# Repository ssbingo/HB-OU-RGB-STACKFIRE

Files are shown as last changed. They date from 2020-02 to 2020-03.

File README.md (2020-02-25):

# HB-OU-RGB-STACKFIRE - Kaminfeuer Leuchte

Viele Projekte haben sich mit der Steuerung von WS2812B-LED's befasst. 
Eigentlich wollte ich aus dem Tee-Licht-Projekt vom [pafra-123](https://github.com/pafra-123/HB_LED_Teelicht) einen kleinen Kamin für die Weihnachtskrippe machen.
Daraus enstand der Gedanke an eine etwas größere Kamin-/Lagerfeuer-Simulation. 
Irgendwo fand ich dann das Projekt einer Nachttischlampe.
Im Großen und Ganzen ganz hübsch, mir jedoch zu klein. Ich wollte es als Raumdeko, als Hingucker bei der Gartenparty und als gemütliches Highlight abends vor dem Wohnwagen. Und ich wollte es Homematic-gebunden haben. Da fand ich den [RGB-Controler](https://github.com/jp112sdl/HB-UNI-RGB-LED-CTRL) von Jérôme(jp112sdl).<br>
So verschmolzen Teile diverser Projekte zu einem Neuen.

## Bilder

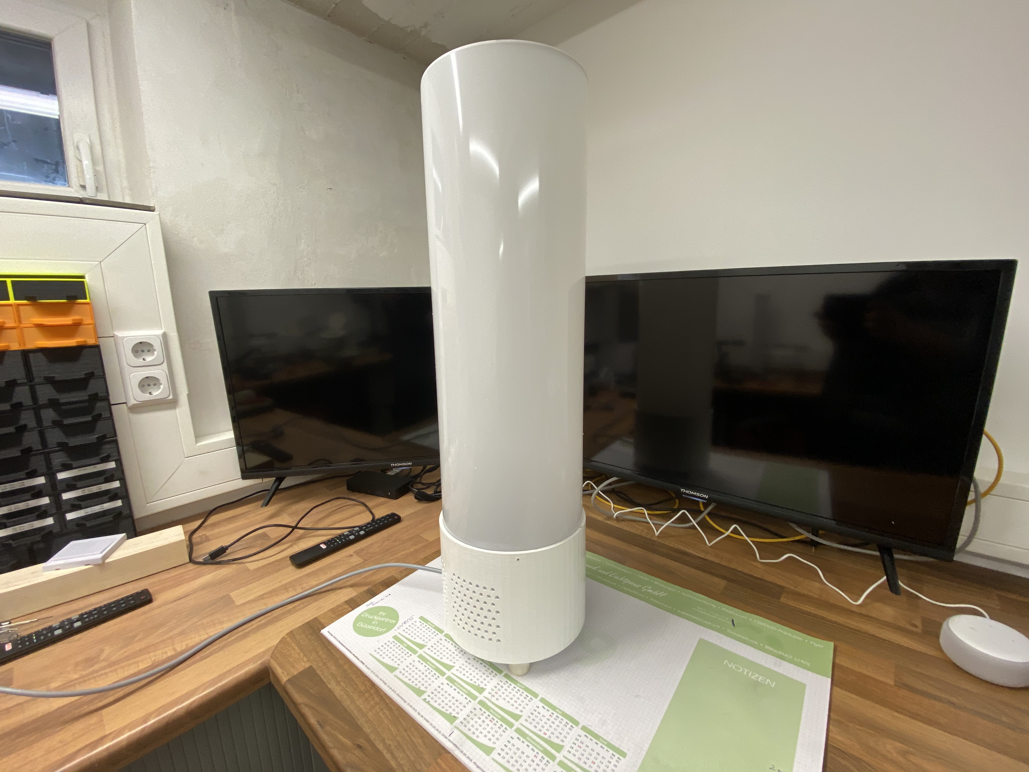
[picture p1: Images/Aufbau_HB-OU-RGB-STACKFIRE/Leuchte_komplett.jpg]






## Konfiguration
### auf der Platine
Die aktuelle Version der PCB verfügt über einen 2-fach Jumper J4 (VCC). Dieser ermöglicht es, die Leuchte ohne das [AZDelivery 5 x 220V zu 5V Mini-Netzteil](https://www.amazon.de/gp/product/B07V7GHK51/ref=ppx_yo_dt_b_asin_title_o06_s00?ie=UTF8&psc=1) zu betreiben. Die Schaltung wird dann über das erste Netzteil der Stripes mit versorgt.<br>
:exclamation:Die Jumper dürfen auf keinen Fall gesteckt werden, wenn das Mini-Netzteil auf der Platine verbaut ist.
Mit dem Einsatz des Mini-Netzteiles habe ich die Möglichkeit, über den im Boden eingauten Schalter, die Netzteile der LED's abzuschalten, ohne dabei den Mega2560 vom Netz zu nehmen. Es kommen somit keine Servicemeldungen über ein "nicht erreichbares Gerät"

### im SourceCode
Die Leuchte ist so geplant, dass sie entwerder mit 10 Stripes á 30LED's oder mit 20 Stripes á 30LED's bestückt werden kann.
Die beiden Netzteile im Grundgehäuse versorgen jeweils immer jeden 2. Ausgang.<br>
Das Grundgehäuse hat für die Befestigung der Netzteile entsprechende Bohrungen(Abstandshalter).<br><br>

In Zeile 20 muss bei voller Bestückung der Paramter<br> #define doubleLED<br> gesetzt werden.<br> Bei halber Bestückung entsprechend auskommentieren.<br><br>

Die Zeilen 30-75 definieren die Anzahl der LED's je Stripe sowie die entsprechenden Ports der Arduino Mega 2560 Core.<br><br>

In den Zeilen 88-117 kann das Verhalten des FireProgramm's in Intensität (Sparking) und Flammenhöhe (Cooling) nach Bedarf angepasst werden.
Derzeit sind nur die letzten 3 Programme (Lagerfeuer, Wasserfall, TV-Simulation) als Feuer verknüpft.<br>
siehe: RGBCtrl.h Zeile 748-772 RGBProgramFire1(brightness,"1-6");<br><br>

In den Zeilen 123-144: FastLED liefert von Haus aus diverse Farbpaletten mit. Für ein Lagerfeuer haben sich bisher Nr.10 (HeatColors_p) oder Nr.11 (LavaColors_p) bewährt.<br><br>

## Schaltplan

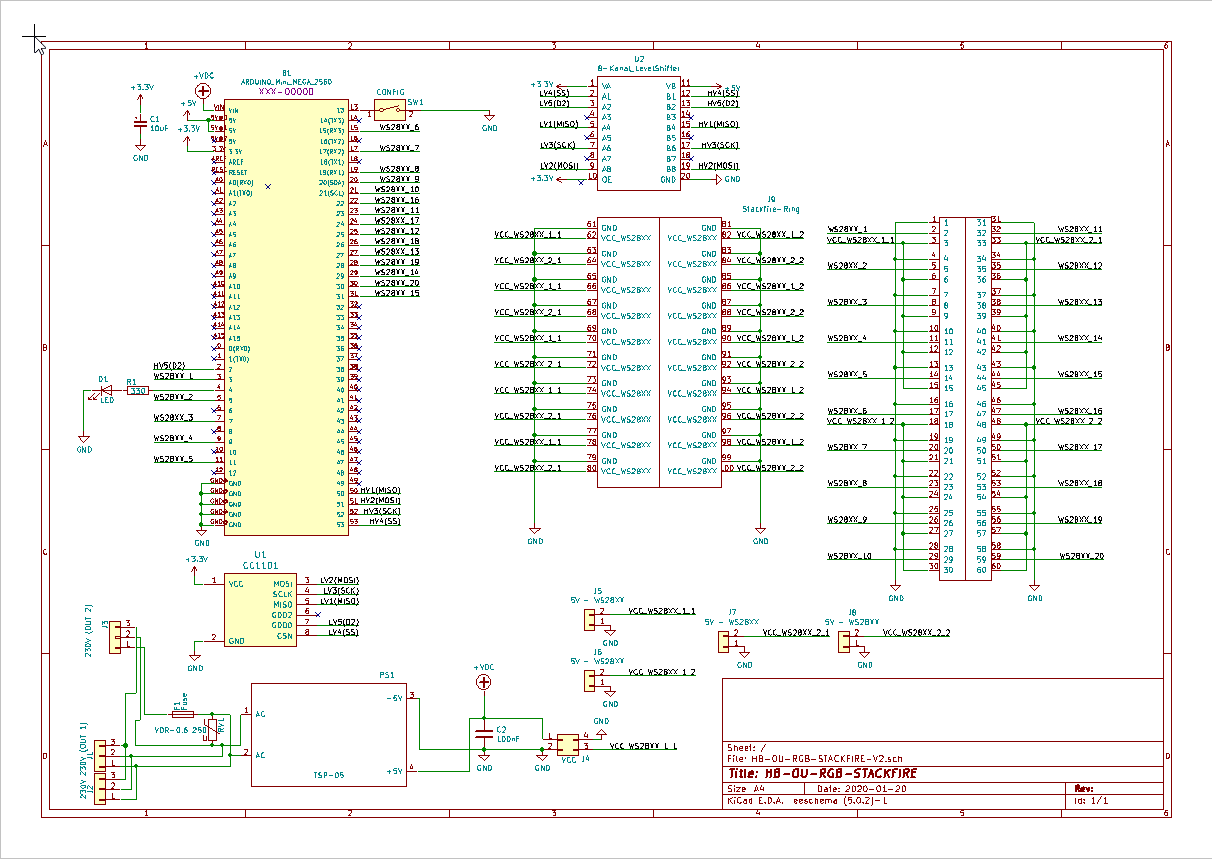
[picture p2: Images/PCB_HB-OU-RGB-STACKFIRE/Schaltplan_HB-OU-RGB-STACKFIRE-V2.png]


[:arrow_right: Schaltplan](Images/PCB_HB-OU-RGB-STACKFIRE/Schaltplan_HB-OU-RGB-STACKFIRE-V2.pdf)

## Platine

[:arrow_right: PCB Gerber](Platine/HB-OU-RGB-STACKFIRE(Mega2560)-V2/HB-OU-RGB-STACKFIRE-V2.zip)

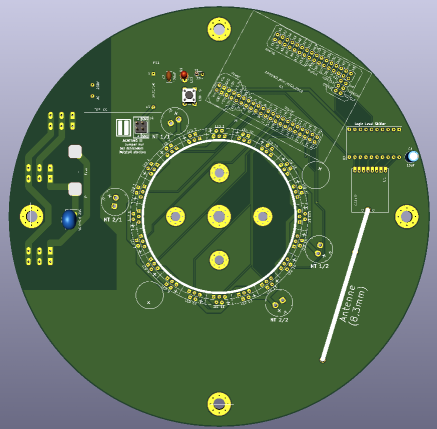
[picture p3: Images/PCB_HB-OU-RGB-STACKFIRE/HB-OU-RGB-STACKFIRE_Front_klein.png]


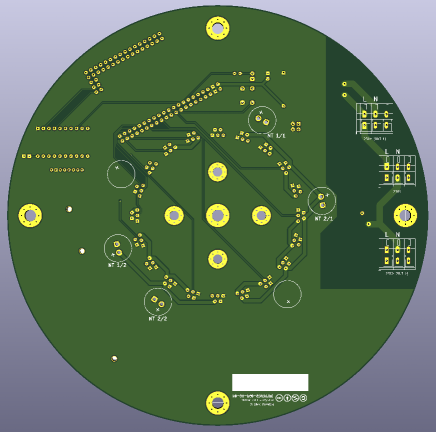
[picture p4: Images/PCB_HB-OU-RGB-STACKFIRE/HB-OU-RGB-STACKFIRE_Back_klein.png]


## Gehäuse

Das Gehaäuse ist ein 3D-Druck. Auf Grund der Größe ist hier mindestens ein Druckbereich von 220x220x200 erforderlich.
(ANET A8/A6/A10 o.ä).
Der Sockel besteht auf dem [Grundgehäuse](Gehäuse/Stack-Fire-Leuchte_Sockel_V1.stl) und der [Auflageplatte](Gehäuse/Stack-Fire-Leuchte_Sockel_Platine_V1.stl) für de Platine.
Desweiteren werden noch 2 Abschlussdeckel [oben](Gehäuse/Stack-Fire-Leuchte_Deckel_ALU_oben_V1.stl) und [unten](Gehäuse/Stack-Fire-Leuchte_Deckel_ALU_unten_V1.stl) für das AluRohr benötigt. 
Ich nutze zum drucken PETG. 

## Aufbau / Stückliste

### Der Aufbau
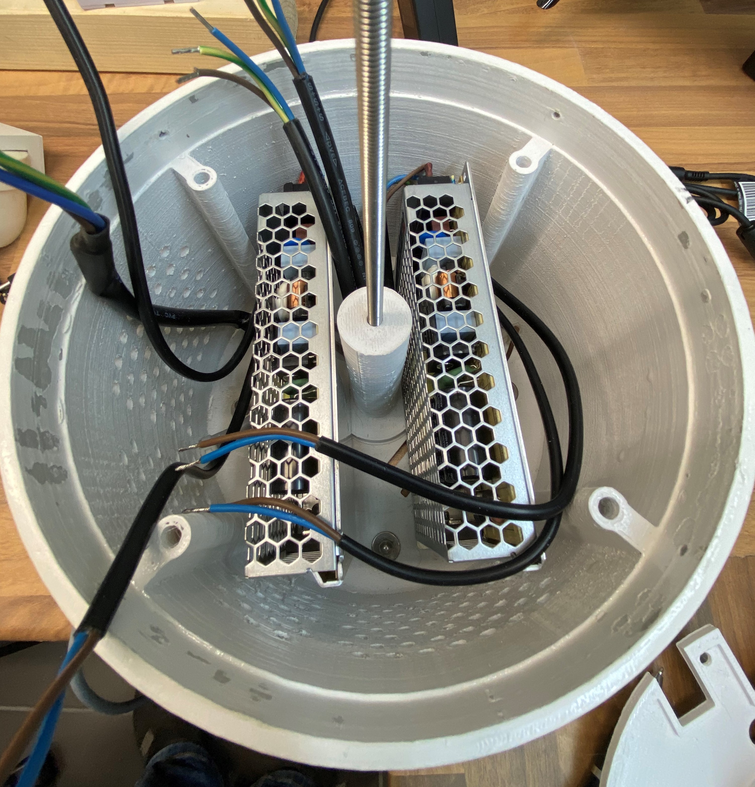
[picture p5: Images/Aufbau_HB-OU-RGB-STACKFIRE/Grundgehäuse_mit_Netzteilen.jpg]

Grundgehäuse mit Netzteilen<br>

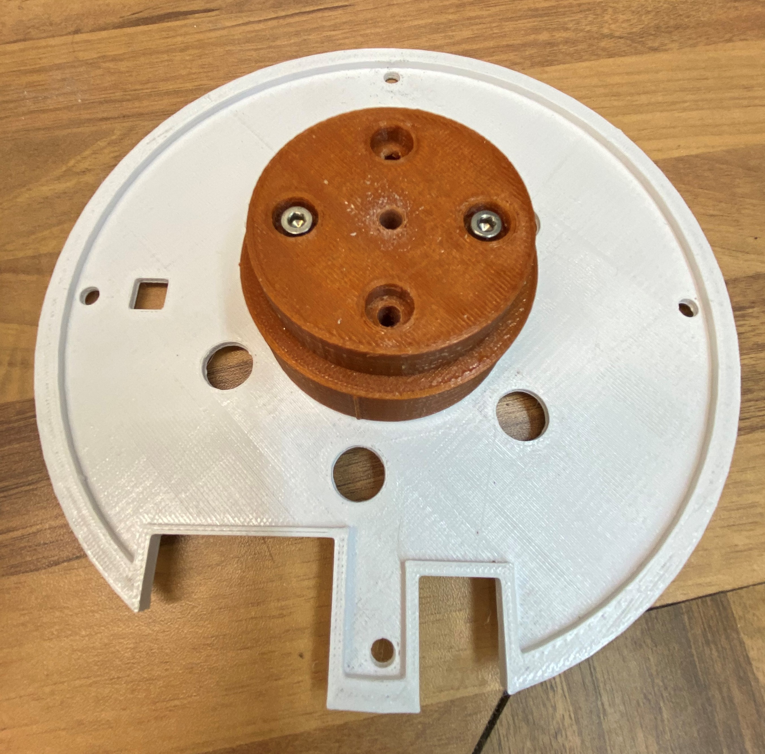
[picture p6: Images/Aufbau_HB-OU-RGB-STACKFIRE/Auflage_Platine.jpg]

Auflage für die Platine<br>

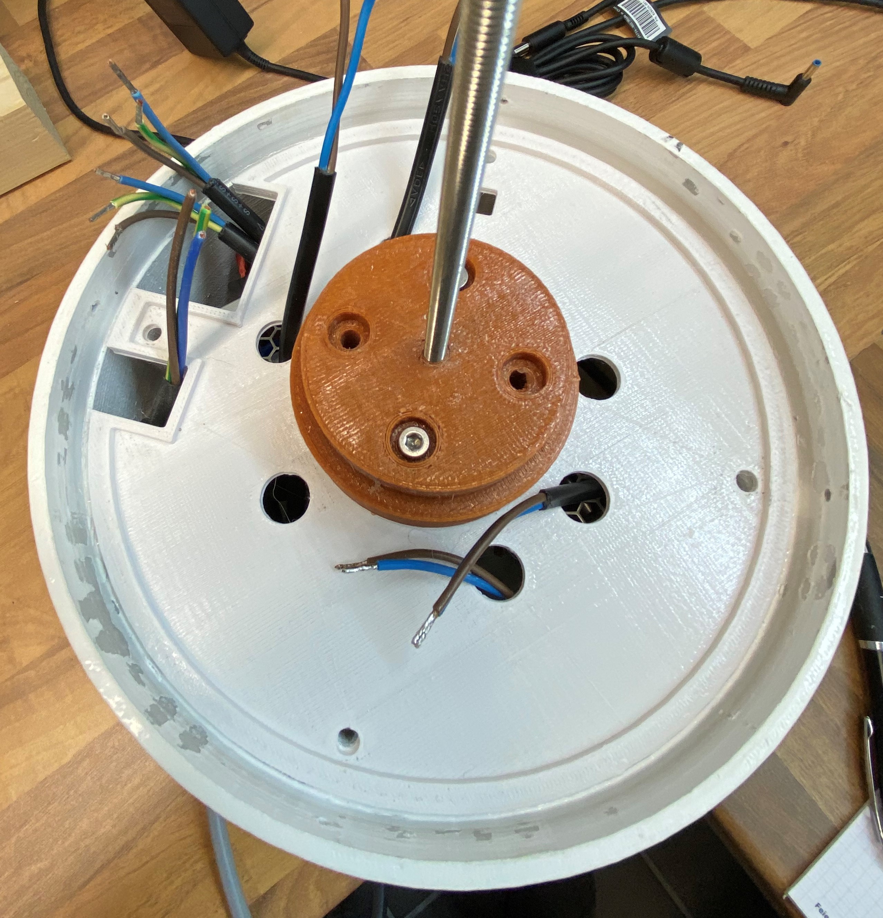
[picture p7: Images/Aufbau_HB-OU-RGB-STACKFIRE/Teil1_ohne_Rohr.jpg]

Einbau der Auflage mit Verschraubung des Rohrhalters<br>

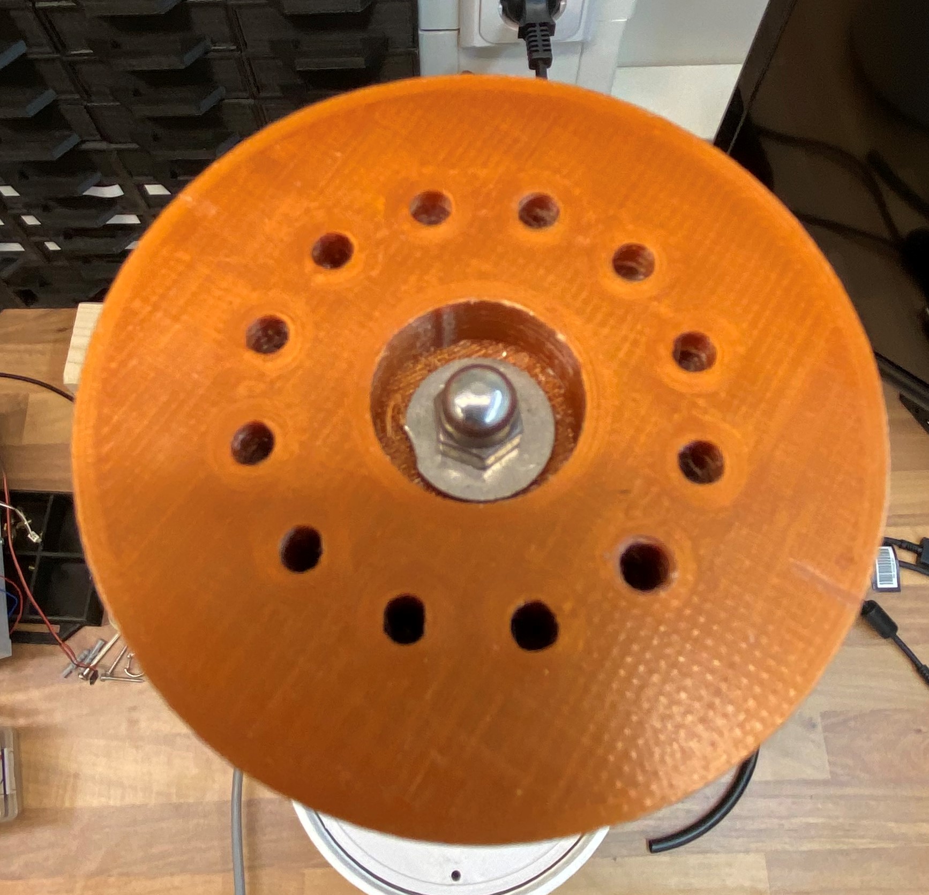
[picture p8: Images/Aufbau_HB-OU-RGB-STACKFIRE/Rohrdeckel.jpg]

Rohrdeckel mit Verschraubung<br>

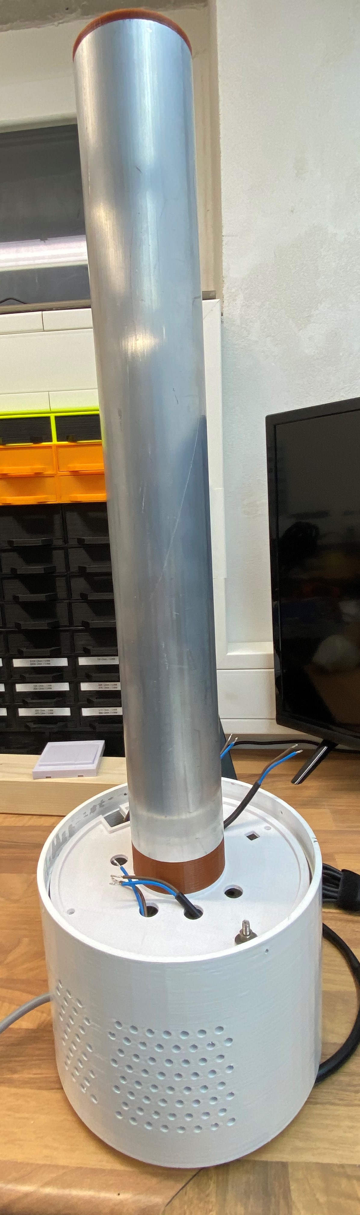
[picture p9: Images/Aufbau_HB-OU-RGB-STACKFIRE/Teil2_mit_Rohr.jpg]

Montage des Alurohrs (dieses wird vor Anbringen der LED-Stripes komplett mit dem Wärmeleitklebeband beklebt<br>

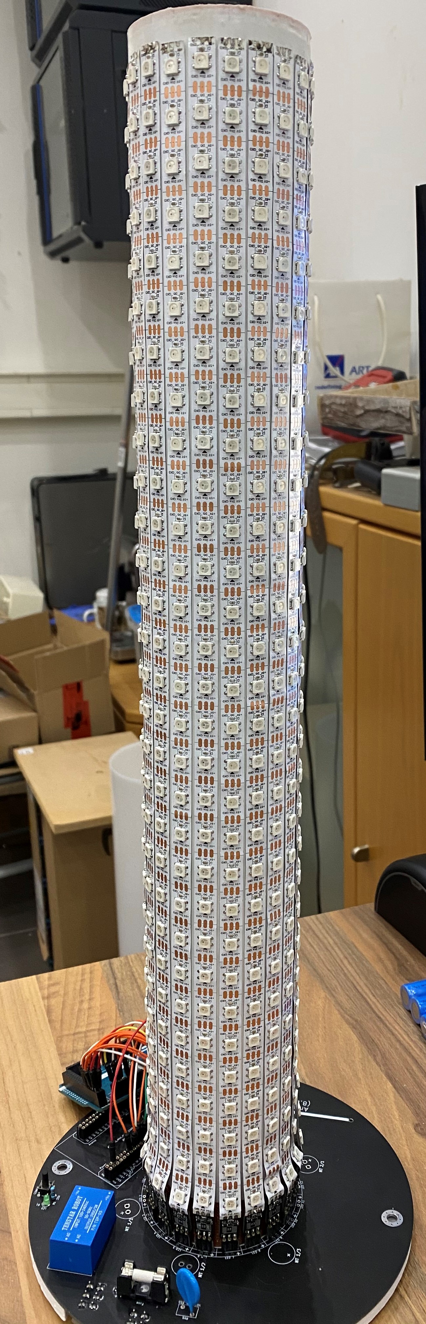
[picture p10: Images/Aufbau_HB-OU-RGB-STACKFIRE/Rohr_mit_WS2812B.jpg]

Rohr mit voller Bestückung 20x30LED<br>

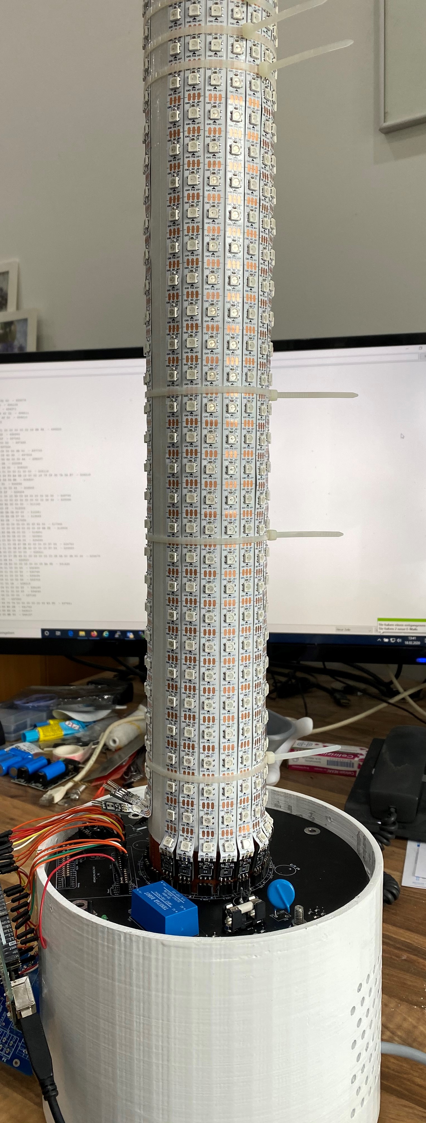
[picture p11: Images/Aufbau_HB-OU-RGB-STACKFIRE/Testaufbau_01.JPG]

Testaufbau Teil 1<br>

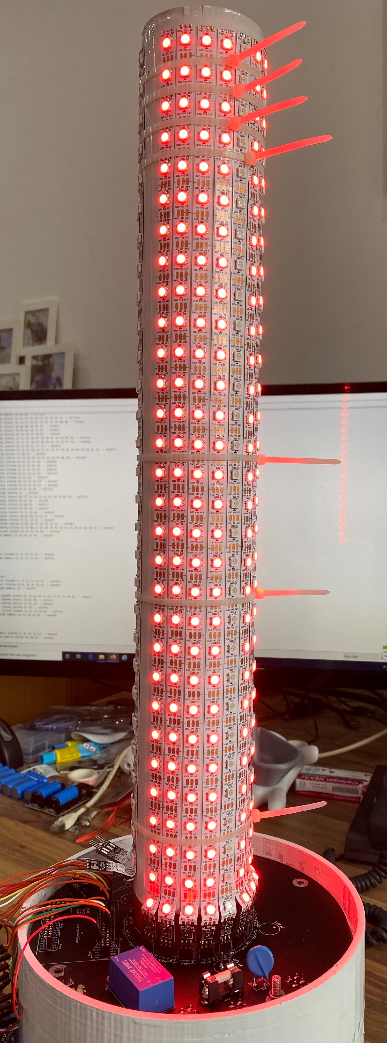
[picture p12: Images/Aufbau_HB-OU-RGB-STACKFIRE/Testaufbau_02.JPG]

Testbaubau Teil 2<br>

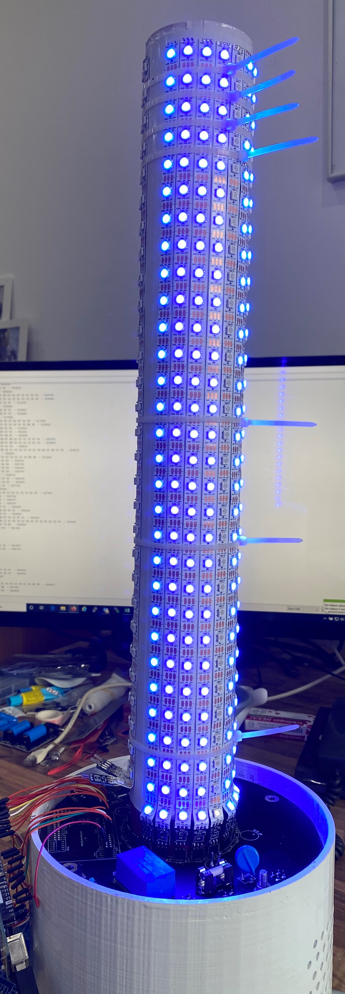
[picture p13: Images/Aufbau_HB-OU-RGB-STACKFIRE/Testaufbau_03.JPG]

Testaufbau Teil 3<br>

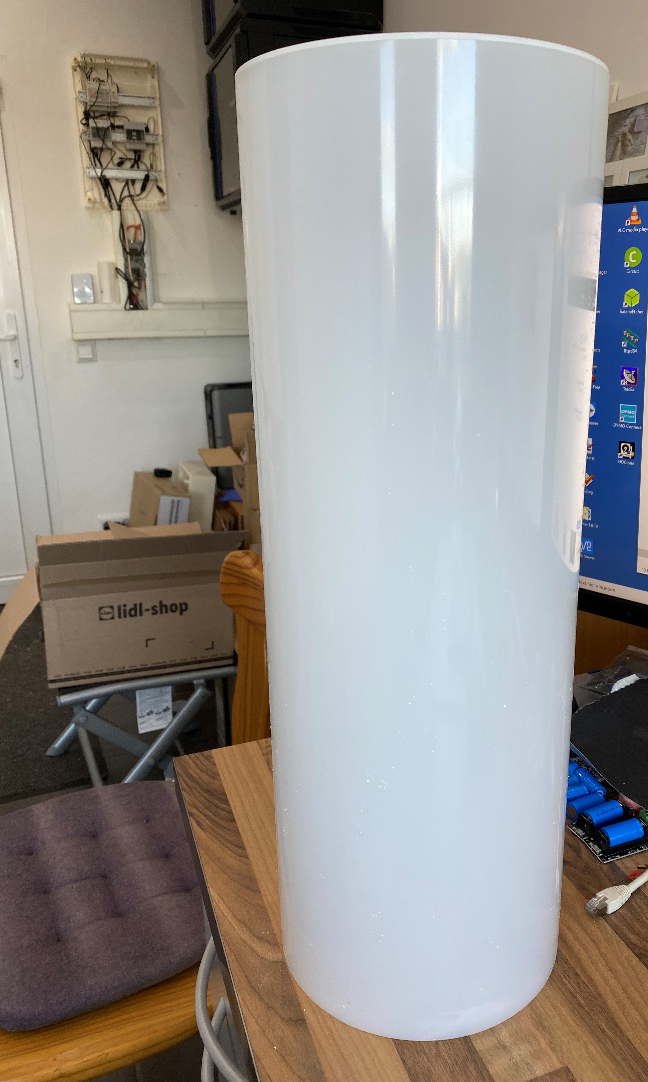
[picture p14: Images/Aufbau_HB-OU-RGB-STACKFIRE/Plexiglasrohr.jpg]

Das Plexiglasrohr. Dieses wird am Ende einfach auf das Grundgehäuse gesteckt und kann bei Bedarf mit 4 Schrauben fixiert werden.<br>

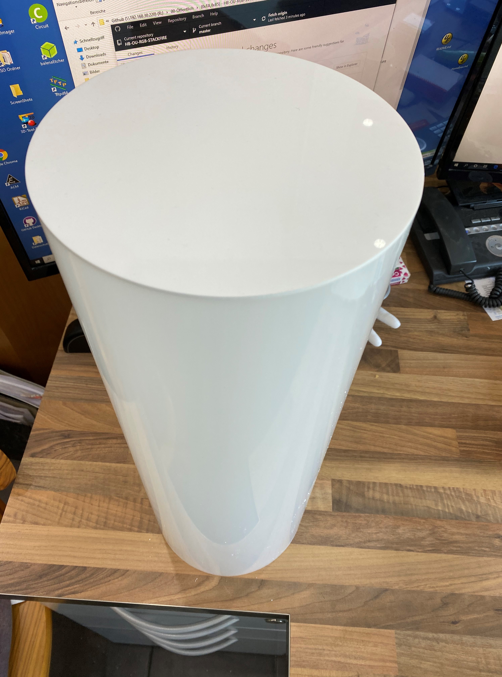
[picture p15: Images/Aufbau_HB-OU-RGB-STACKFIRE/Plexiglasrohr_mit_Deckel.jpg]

Der passende Deckel kann direkt mit bestellt werden. Er ist so gefrässt, dass er passgenau auf das Rohr geklebt werden kann<br>

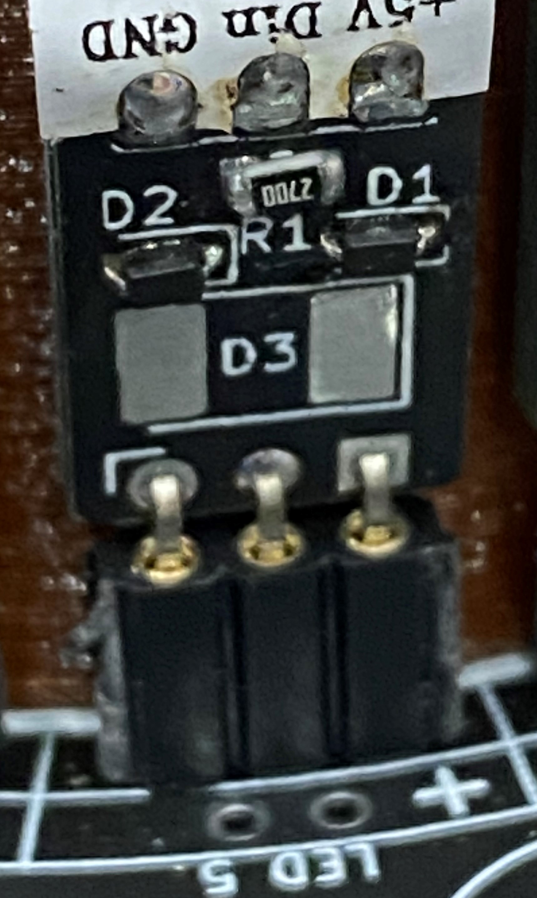
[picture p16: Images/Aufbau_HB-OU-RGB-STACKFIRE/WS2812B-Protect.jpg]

Prototype der WS2812B-Protect Platine. Diese wird nach der Bestückung direkt an den Stripe gelötet. Als Steckverbinder habe ich von gewinkelten Pinleisten (Raster 2.54) einfach die Stifte einzeln genommen. Ist viel Fummelei... <br>

### Die benötigten Bauteile
| Bauteil | Link |
| ---|---|
|50cm Alurohr Länge: 0,5-3 m Aluminium Rohr Alu Profil Rundrohr AlMgSi0,5 Modellbau | [:arrow_right: Ebay](https://www.ebay.de/itm/Alurohr-L%C3%A4nge-0-5-3-m-Aluminium-Rohr-Alu-Profil-Rundrohr-AlMgSi0-5-Modellbau/222169076786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) |
|55cm  PLEXIGLAS® XT Rohr 3mm weiß 200/194mm Durchmesser | [:arrow_right: Ebay](https://www.ebay.de/itm/PLEXIGLAS-XT-Rohr-3mm-wei%C3%9F-200-194mm-Durchmesser-74-00-lfdm/112415674967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) |
|PLEXIGLAS® Deckel 4 mm weiß Ø freiwählbar passend für unsere PLEXIGLAS® XT Rohr | [:arrow_right: Ebay](https://www.ebay.de/itm/PLEXIGLAS-Deckel-4-mm-wei%C3%9F-%C3%98-freiw%C3%A4hlbar-passend-f%C3%BCr-unsere-PLEXIGLAS-XT-Rohre/122355660437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)|
|WS2812B-Protect | [:arrow_right: Reichelt Bestell-Liste](https://www.reichelt.de/my/1667564) |
|Limeow Thermisch Klebeband Wärmeleitendes Doppelseitiges Klebeband Selbstklebend Tape Wärmeleitpaste Thermal Compound Thermische Verbindung Paste Kühlkörper Leitfähiges Kühlband Doppelseitig Klebend | [:arrow_right: Amazon](https://www.amazon.de/gp/product/B07FPKVML7/ref=ppx_yo_dt_b_asin_title_o05_s00?ie=UTF8&psc=1) |
|AZDelivery 5 x 220V zu 5V Mini-Netzteil für Arduino und Raspberry Pi | [:arrow_right: Amazon](https://www.amazon.de/gp/product/B07V7GHK51/ref=ppx_yo_dt_b_asin_title_o06_s00?ie=UTF8&psc=1) |
|MW LRS-150F-5 Schaltnetzteil, geschlossen, 110 W, 5 V, 22 A | [:arrow_right: Reichelt](https://www.reichelt.de/schaltnetzteil-geschlossen-110-w-5-v-22-a-mw-lrs-150f-5-p202979.html?&nbc=1)|
| | |
|Bauteileliste Reichelt (incl. der benötigten Netzteile)| [:arrow_right: Reichelt](https://www.reichelt.de/my/1677743)|

## Hinweise

- :exclamation: Viele Projekte verweisen auf Probleme mit dem WS2812B. Die Schutzschaltung WS2812B-Protect ist eine kleine 17x10mm Platine, welche die Stripes schützen soll. Sie ist je nach eigenem Ermessen einbaubar. 

## CCU2/CCU3/RaspberryMatic Installation

Einstellungen/Systemsteuerung/Zusatzsoftware -> Datei 

Ich nutze das AddOn von Jérôme (jp112sdl) [JP-HB-Devices-addon](https://github.com/jp112sdl/JP-HB-Devices-addon).
In dieses bzw. dessen Struckture müssen die Dateien aus dem Verzeichniss [AddOn](AddOn) entsprechend selbst eingebunden werden und das AddOn dann installiert werden.

## Benötige Libraries

 - [FastLED](https://github.com/FastLED/FastLED)
 - [AskSinPP](https://github.com/pa-pa/AskSinPP)
   - sowie die dort aufgeführten [zusätzlichen Bibliotheken](https://github.com/pa-pa/AskSinPP#required-additional-arduino-libraries)

## Lizenz

**Creative Commons BY-NC-SA**<br>
Give Credit, NonCommercial, ShareAlike

<br />This work is licensed under a <a rel="license" href="http://creativecommons.org/licenses/by-nc-sa/4.0/">Creative Commons Attribution-NonCommercial-ShareAlike 4.0 International License</a>.

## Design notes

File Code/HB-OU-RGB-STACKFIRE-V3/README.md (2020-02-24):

Code ist experimentell für den Einsatz eines externen Tasters als Steuerelement für den Dimmer.
Derzeit ist der Code in Bezug auf den Taster nicht funktionsfähig

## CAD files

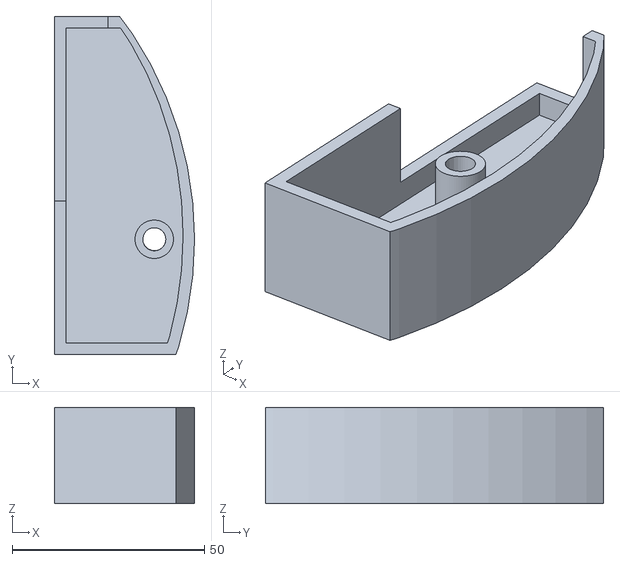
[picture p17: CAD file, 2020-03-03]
Gehäuse/Stack-Fire-Leuchte_Griffschutz.stl
36.5 x 88.0 x 25.0

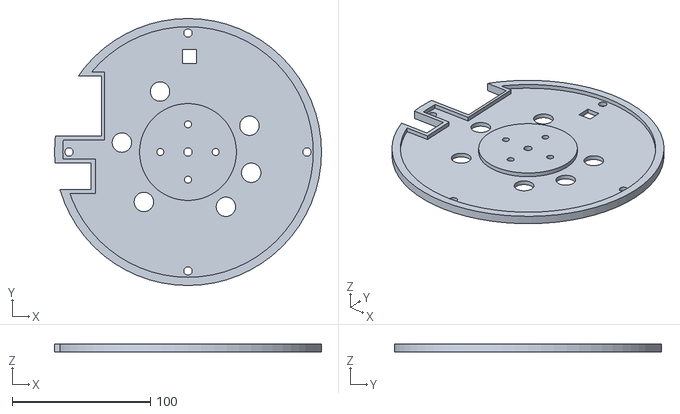
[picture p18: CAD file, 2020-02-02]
Gehäuse/Stack-Fire-Leuchte_Sockel_Platine_V1.stl
193.0 x 193.0 x 6.00

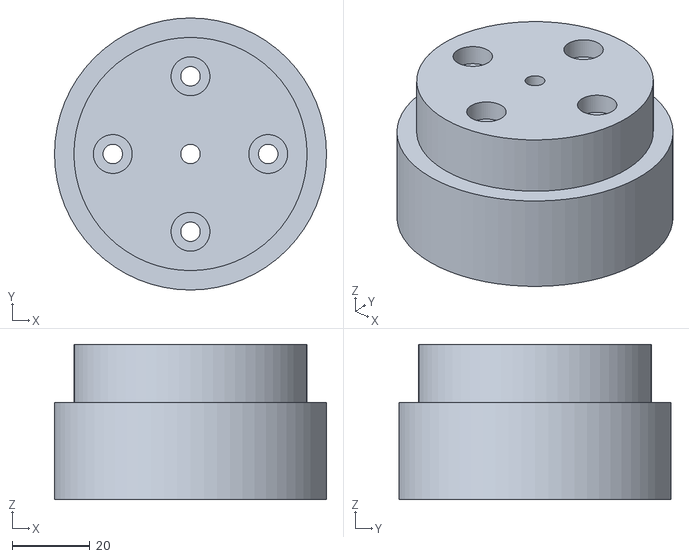
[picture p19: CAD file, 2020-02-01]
Gehäuse/Stack-Fire-Leuchte_Deckel_ALU_unten_V1.stl
70.0 x 70.0 x 40.0

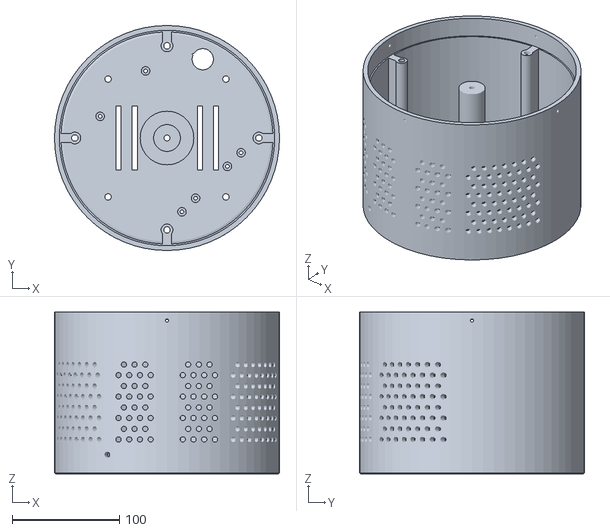
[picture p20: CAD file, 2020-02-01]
Gehäuse/Stack-Fire-Leuchte_Sockel_V1.stl
210.0 x 210.0 x 150.7

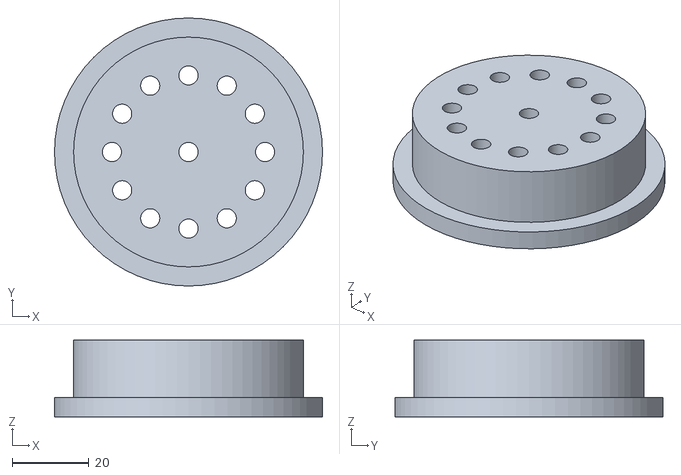
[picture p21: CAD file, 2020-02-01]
Gehäuse/Stack-Fire-Leuchte_Deckel_ALU_oben_V1.stl
70.0 x 70.0 x 20.0

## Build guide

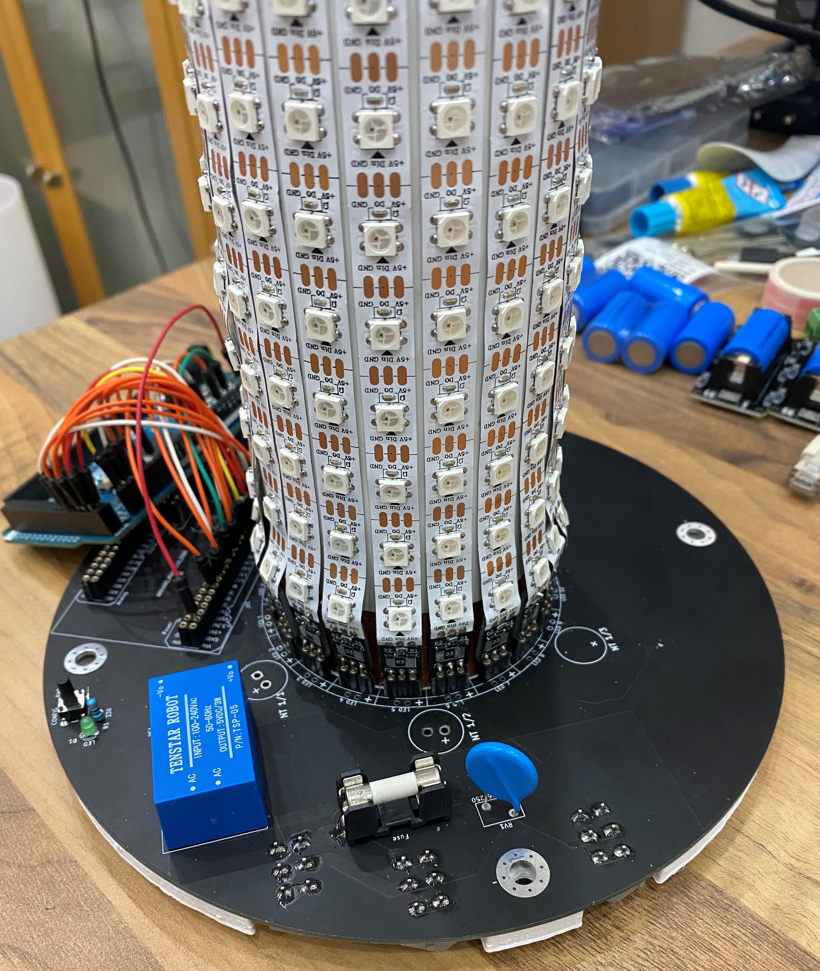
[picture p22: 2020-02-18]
Images/Aufbau_HB-OU-RGB-STACKFIRE/Testaufbau_mit_Platine.jpg

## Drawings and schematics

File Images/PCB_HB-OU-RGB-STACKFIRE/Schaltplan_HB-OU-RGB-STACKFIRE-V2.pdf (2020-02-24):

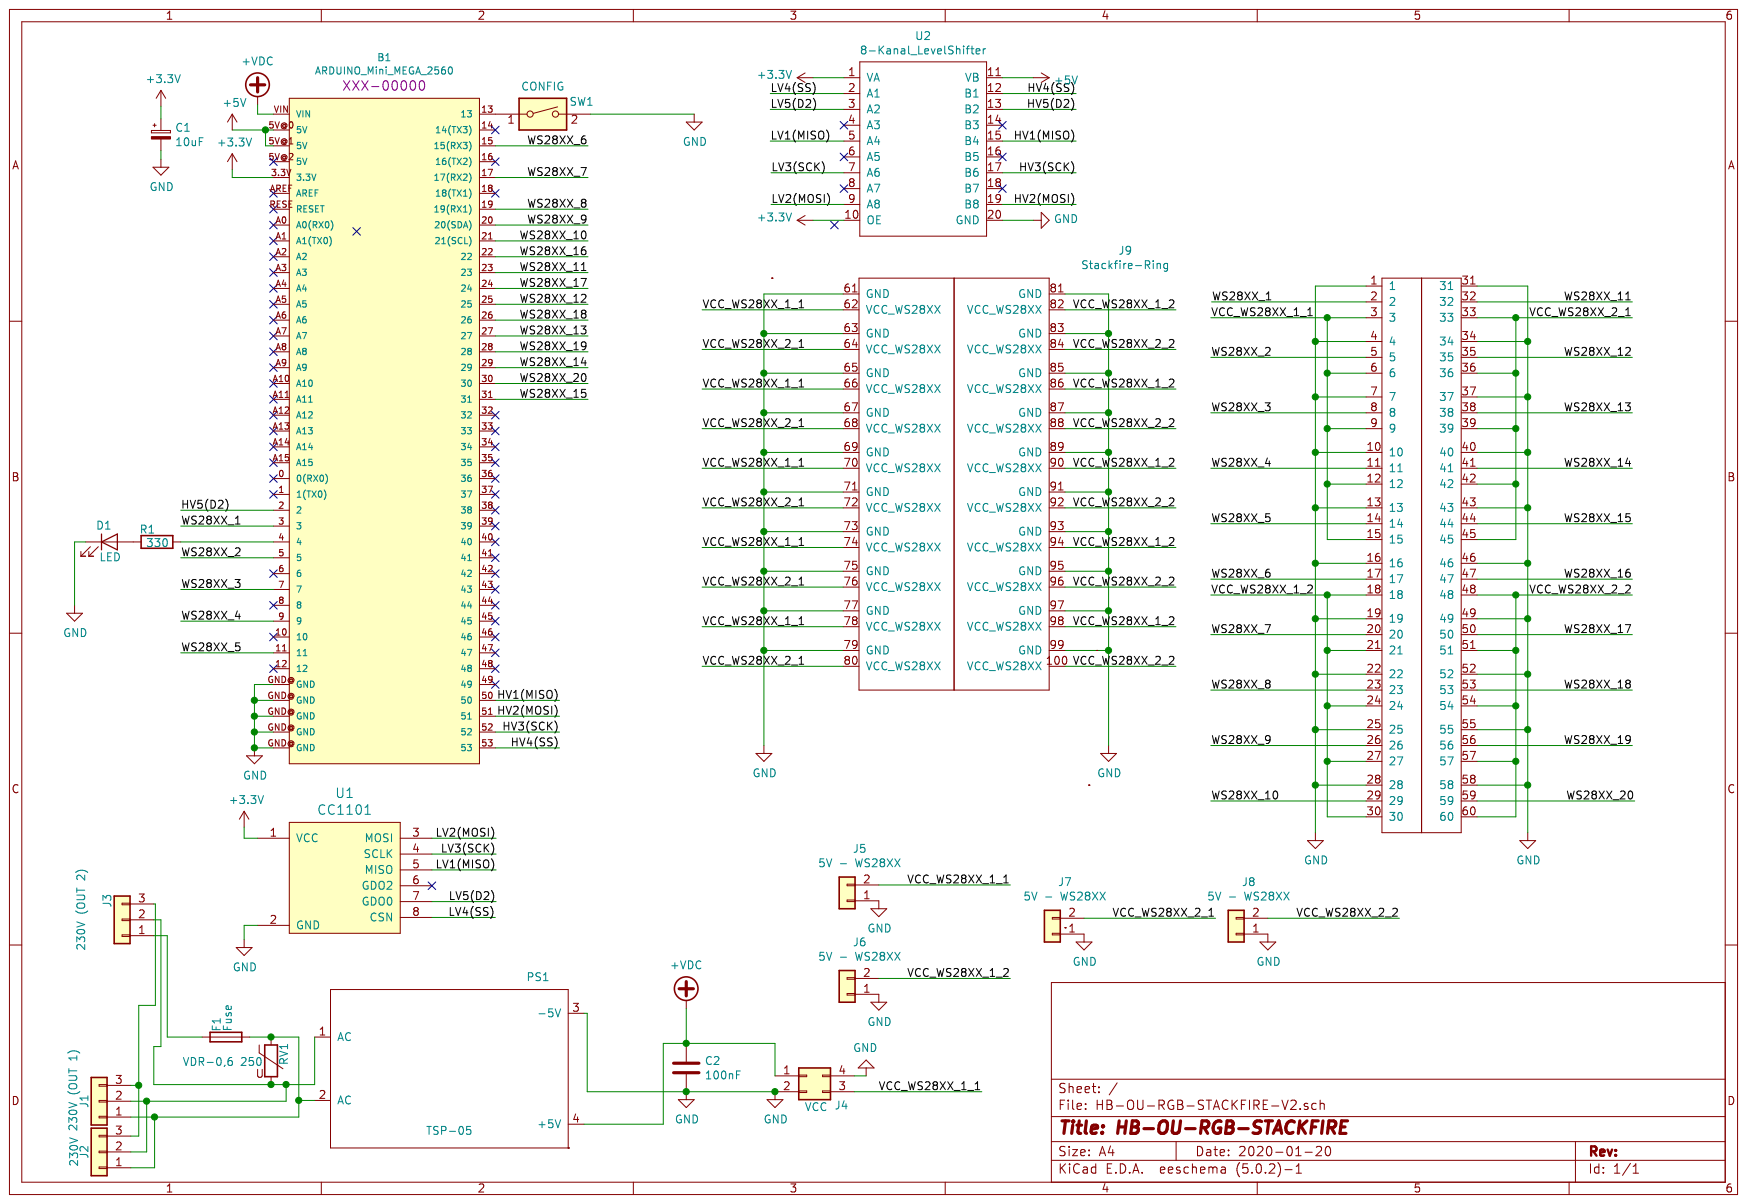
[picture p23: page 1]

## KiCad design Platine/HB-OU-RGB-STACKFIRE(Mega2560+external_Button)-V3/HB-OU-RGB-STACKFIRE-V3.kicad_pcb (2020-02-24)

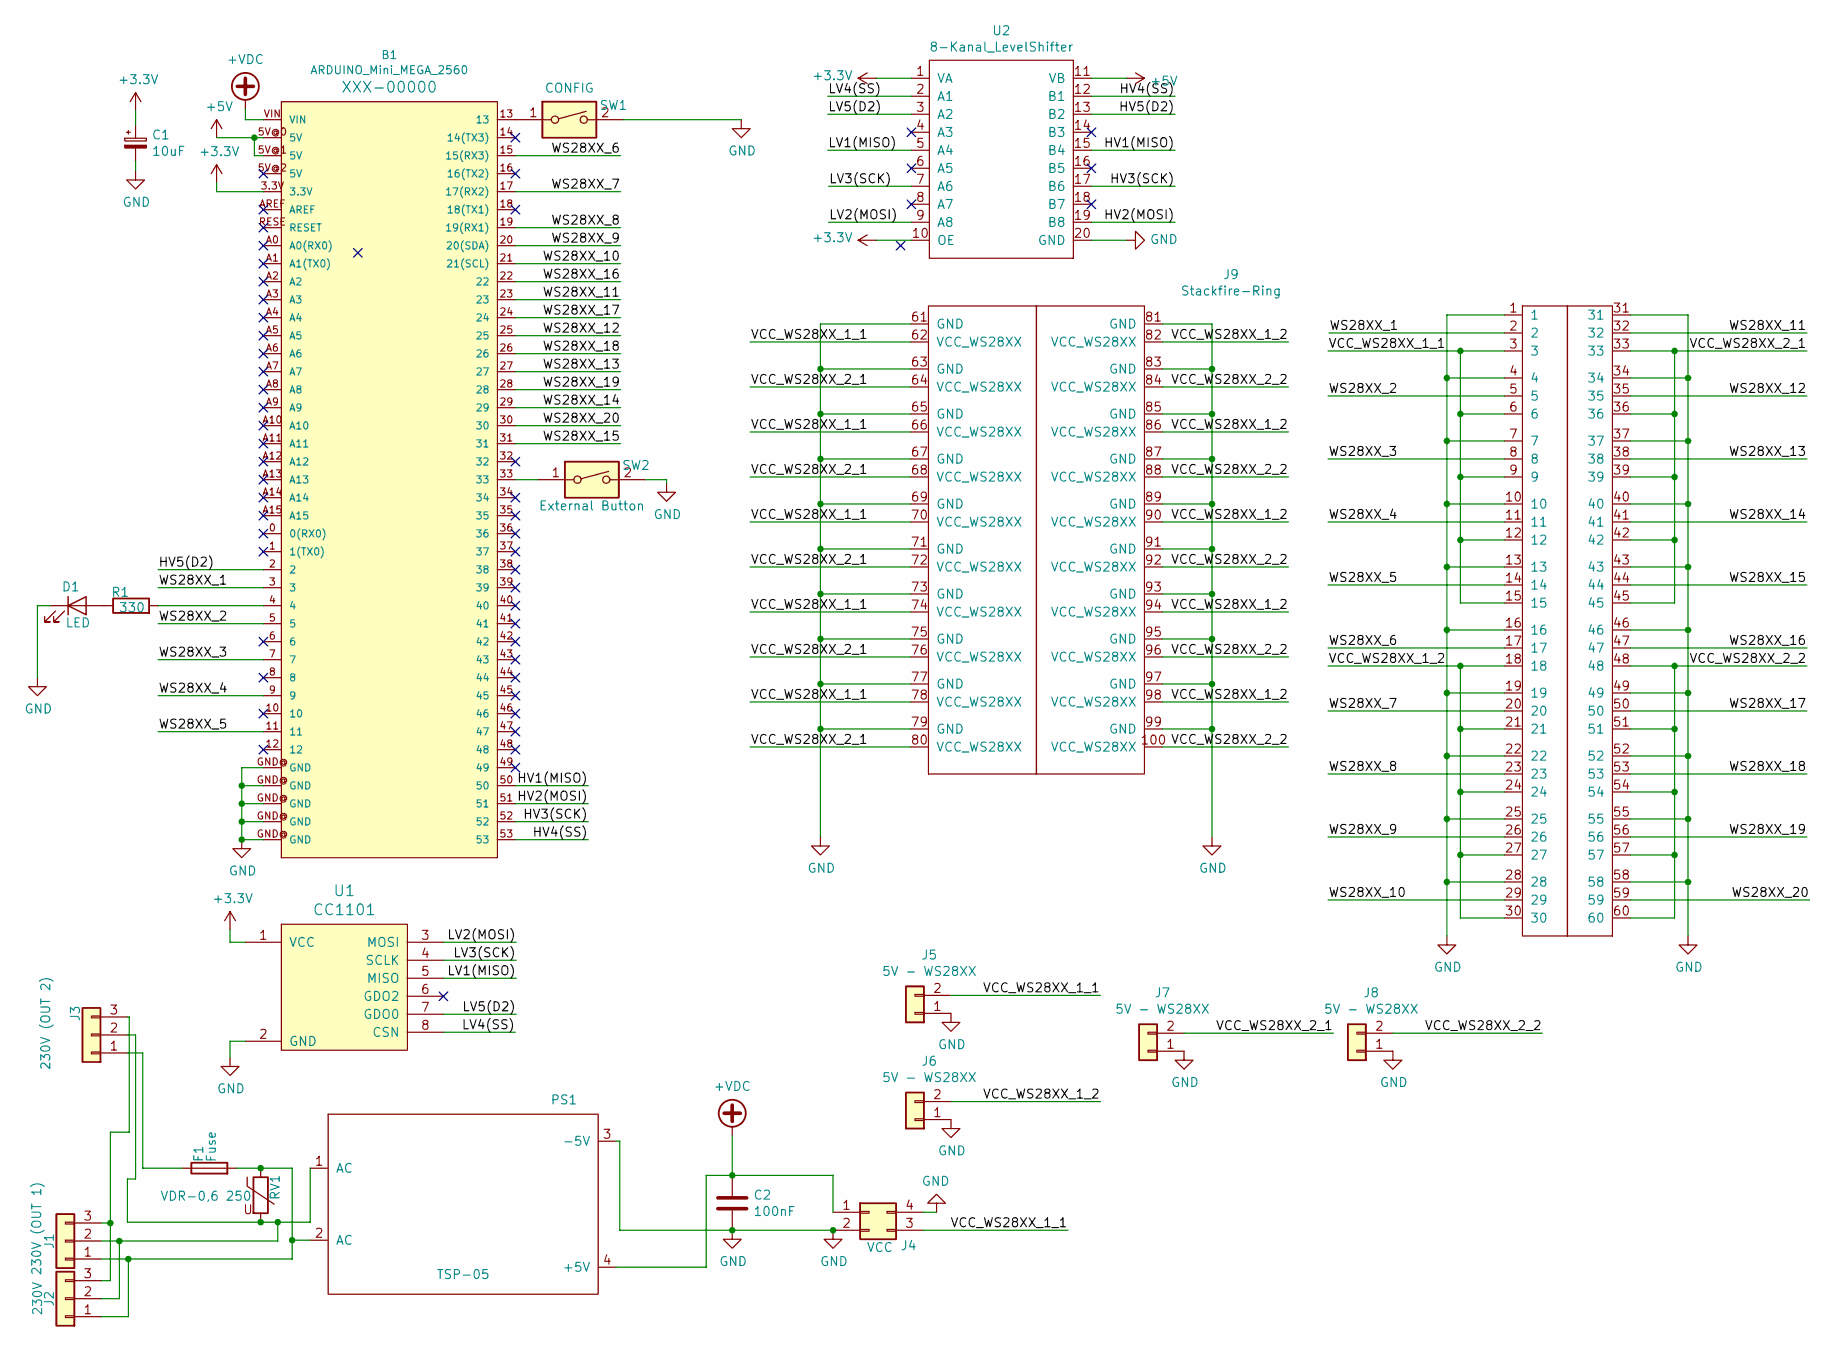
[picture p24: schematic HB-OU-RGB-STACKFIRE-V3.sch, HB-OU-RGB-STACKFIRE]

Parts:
B1: ARDUINO_Mini_MEGA_2560; Mini Mega 2560
C1: 10uF; CP_Radial_D5.0mm_P2.50mm
C2: 100nF; C_Disc_D5.0mm_W2.5mm_P2.50mm
D1: LED; LED_D3.0mm
F1: Fuse; Fuse_Schurter_318265
J1: 230V (OUT 1); TerminalBlock_WAGO_236-103_1x03_P5.00mm_45Degree
J2: 230V; TerminalBlock_WAGO_236-103_1x03_P5.00mm_45Degree
J3: 230V (OUT 2); TerminalBlock_WAGO_236-103_1x03_P5.00mm_45Degree
J4: VCC; PinHeader_2x02_P2.54mm_Vertical
J5, J6, J7, J8: 5V - WS28XX; PinHeader_1x2_P3.96mm_Drill1.6mm
J9: Stackfire-Ring
PS1: TSP-05
R1: 330; R_Axial_DIN0204_L3.6mm_D1.6mm_P2.54mm_Vertical
RV1: VDR-0,6 250; RV_Disc_D9mm_W5.7mm_P5mm
SW1: CONFIG; SW_PUSH_6mm_H5mm
SW2: External Button; PinHeader_1x02_P2.54mm_Vertical
U1: CC1101
U2: 8-Kanal_LevelShifter; Adafruit 8-Kanal Level Shifter

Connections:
+3V3: B1.3.3V, C1.1, U1.1 (VCC), U2.1 (VA), U2.10 (OE)
+5V: B1.5V@0 (5V), B1.5V@1 (5V), U2.11 (VB)
+VDC: B1.VIN, C2.1, J4.1, PS1.4 (+5V)
/HV1(MISO): B1.50, U2.15 (B4)
/HV2(MOSI): B1.51, U2.19 (B8)
/HV3(SCK): B1.52, U2.17 (B6)
/HV4(SS): B1.53, U2.12 (B1)
/HV5(D2): B1.2, U2.13 (B2)
/LV1(MISO): U1.5 (MISO), U2.5 (A4)
/LV2(MOSI): U1.3 (MOSI), U2.9 (A8)
/LV3(SCK): U1.4 (SCLK), U2.7 (A6)
/LV4(SS): U1.8 (CSN), U2.2 (A1)
/LV5(D2): U1.7 (GDO0), U2.3 (A2)
/VCC_WS28XX_1_1: J4.3, J5.2, J9.3, J9.6, J9.9, J9.12, J9.15, J9.62 (VCC_WS28XX), J9.66 (VCC_WS28XX), J9.70 (VCC_WS28XX), J9.74 (VCC_WS28XX), J9.78 (VCC_WS28XX)
/VCC_WS28XX_1_2: J6.2, J9.18, J9.21, J9.24, J9.27, J9.30, J9.82 (VCC_WS28XX), J9.86 (VCC_WS28XX), J9.90 (VCC_WS28XX), J9.94 (VCC_WS28XX), J9.98 (VCC_WS28XX)
/VCC_WS28XX_2_1: J7.2, J9.33, J9.36, J9.39, J9.42, J9.45, J9.64 (VCC_WS28XX), J9.68 (VCC_WS28XX), J9.72 (VCC_WS28XX), J9.76 (VCC_WS28XX), J9.80 (VCC_WS28XX)
/VCC_WS28XX_2_2: J8.2, J9.48, J9.51, J9.54, J9.57, J9.60, J9.84 (VCC_WS28XX), J9.88 (VCC_WS28XX), J9.92 (VCC_WS28XX), J9.96 (VCC_WS28XX), J9.100 (VCC_WS28XX)
/WS28XX_1: B1.3, J9.2
/WS28XX_2: B1.5, J9.5
/WS28XX_3: B1.7, J9.8
/WS28XX_4: B1.9, J9.11
/WS28XX_5: B1.11, J9.14
/WS28XX_6: B1.15 (15(RX3)), J9.17
/WS28XX_7: B1.17 (17(RX2)), J9.20
/WS28XX_8: B1.19 (19(RX1)), J9.23
/WS28XX_9: B1.20 (20(SDA)), J9.26
/WS28XX_10: B1.21 (21(SCL)), J9.29
/WS28XX_11: B1.23, J9.32
/WS28XX_12: B1.25, J9.35
/WS28XX_13: B1.27, J9.38
/WS28XX_14: B1.29, J9.41
/WS28XX_15: B1.31, J9.44
/WS28XX_16: B1.22, J9.47
/WS28XX_17: B1.24, J9.50
/WS28XX_18: B1.26, J9.53
/WS28XX_19: B1.28, J9.56
/WS28XX_20: B1.30, J9.59
GND: B1.GND@ (GND), C1.2, C2.2, D1.1 (K), J4.2, J4.4, J5.1, J6.1, J7.1, J8.1, J9.1, J9.4, J9.7, J9.10, J9.13, J9.16, J9.19, J9.22, J9.25, J9.28, J9.31, J9.34, J9.37, J9.40, J9.43, J9.46, J9.49, J9.52, J9.55, J9.58, J9.61 (GND), J9.63 (GND), J9.65 (GND), J9.67 (GND), J9.69 (GND), J9.71 (GND), J9.73 (GND), J9.75 (GND), J9.77 (GND), J9.79 (GND), J9.81 (GND), J9.83 (GND), J9.85 (GND), J9.87 (GND), J9.89 (GND), J9.91 (GND), J9.93 (GND), J9.95 (GND), J9.97 (GND), J9.99 (GND), PS1.3 (-5V), SW1.2, SW2.2, U1.2 (GND), U2.20 (GND)
unnamed: B1.4, R1.2
unnamed: B1.13, SW1.1
unnamed: B1.33, SW2.1
unnamed: D1.2 (A), R1.1
unnamed: F1.1, J3.1
unnamed: F1.2, J1.1, J2.1, PS1.2 (AC), RV1.1
unnamed: J1.2, J2.2, J3.2, PS1.1 (AC), RV1.2
unnamed: J1.3, J2.3, J3.3

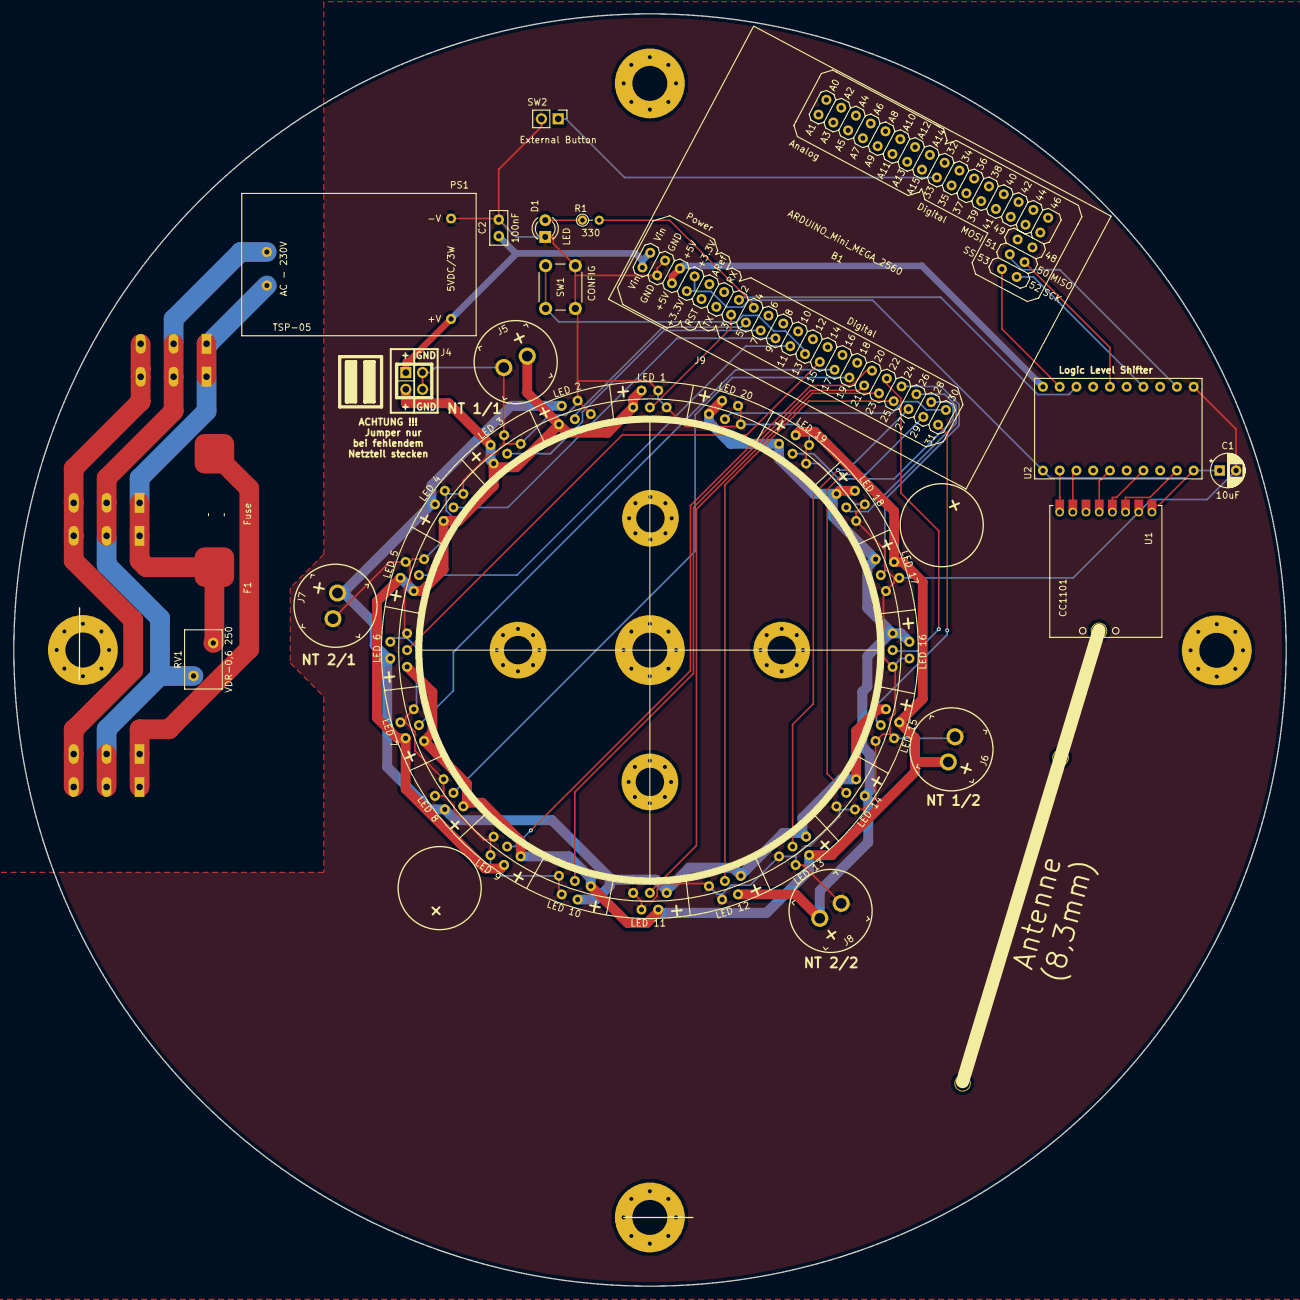
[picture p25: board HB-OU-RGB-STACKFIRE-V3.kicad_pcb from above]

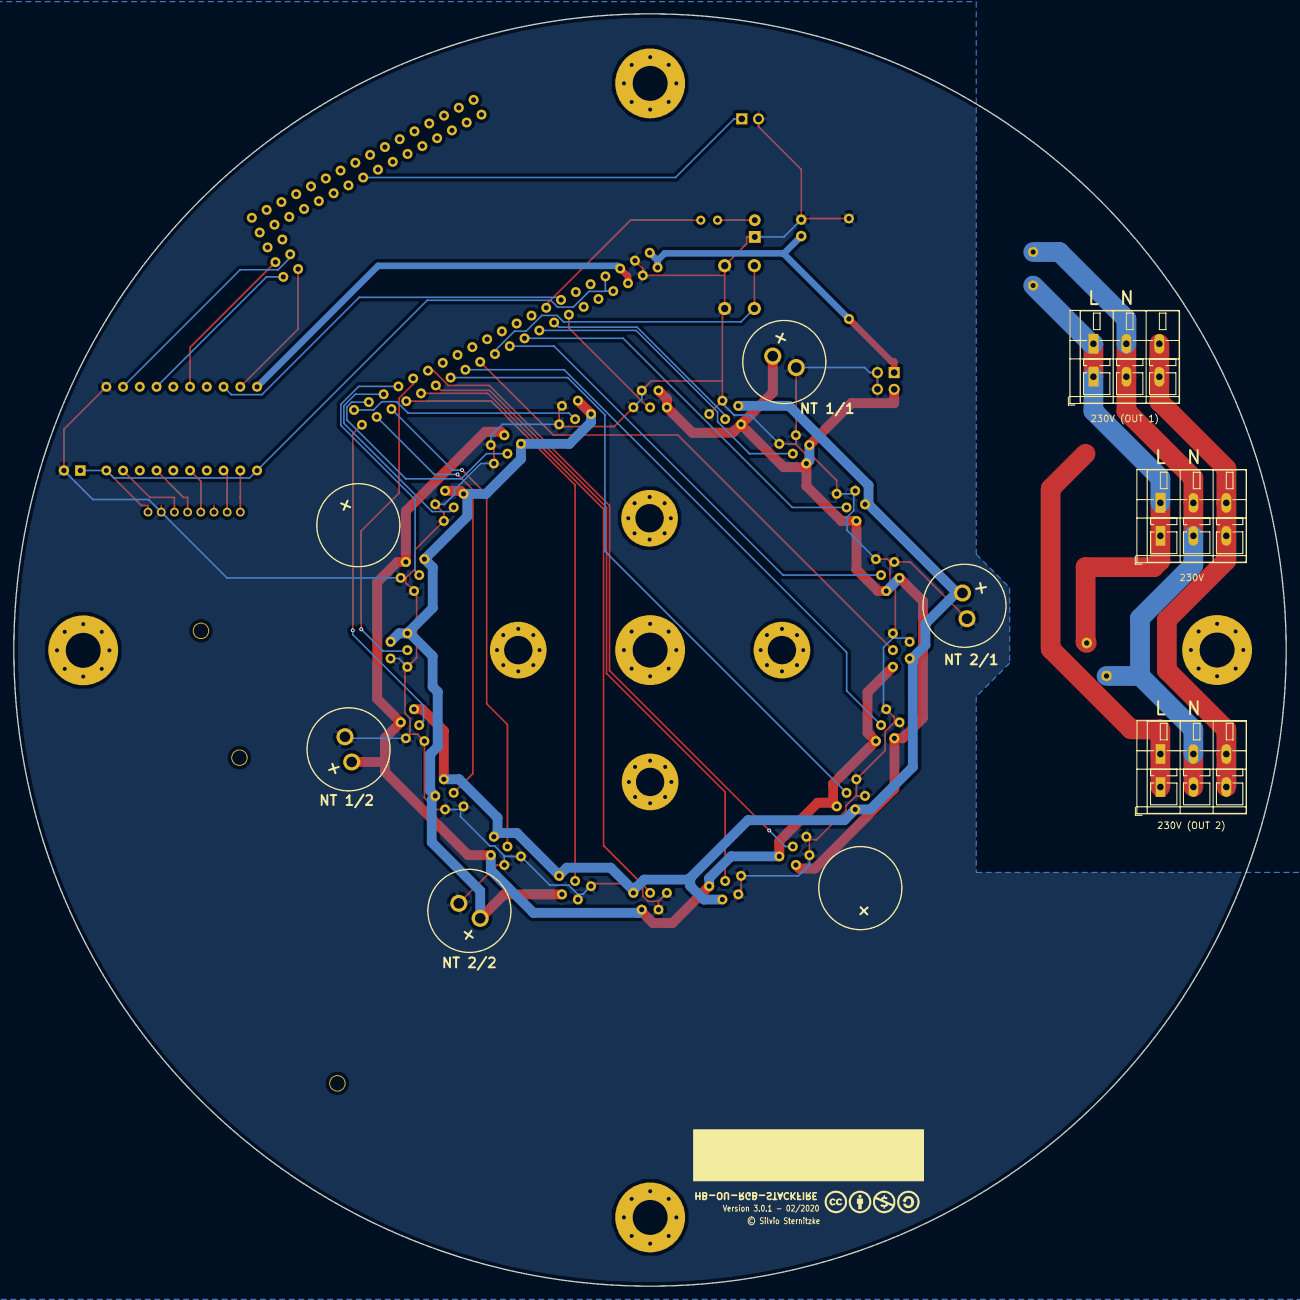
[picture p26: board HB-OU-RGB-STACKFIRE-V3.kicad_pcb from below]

Board: 2 copper layers, 193.0 x 193.0 mm, 34 parts (3 on the bottom side), 46 nets.

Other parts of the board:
Cp1: Version 3.0.1 - 02/2020; Copyrigth
MH1, MH2, MH3: MountingHole_2.2mm_M2_Pad
P1, P2, P3, P4, P5: MountingHole_5.3mm_M5_Pad_Via
P11, P12, P13, P14: MountingHole_4.3mm_M4_Pad_Via

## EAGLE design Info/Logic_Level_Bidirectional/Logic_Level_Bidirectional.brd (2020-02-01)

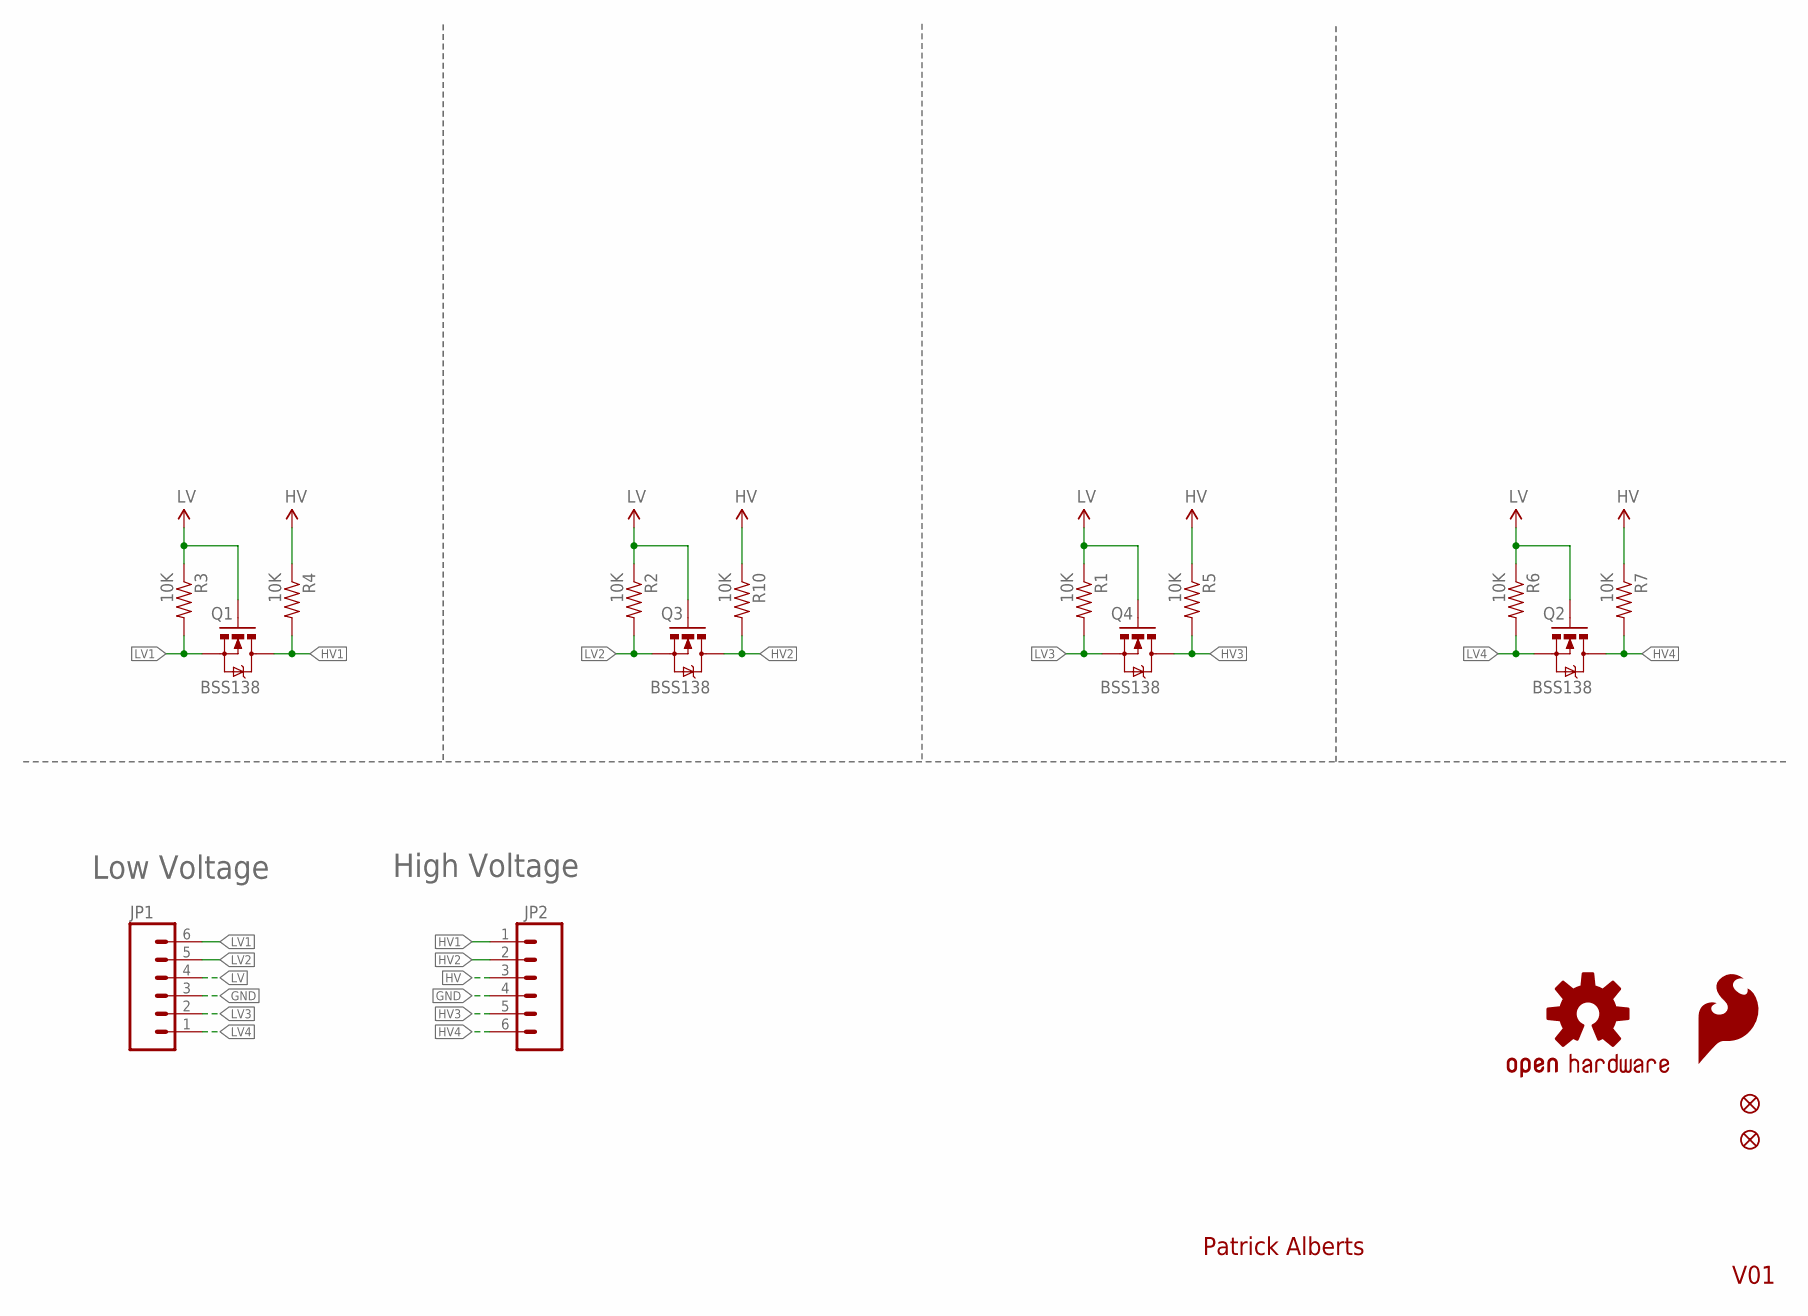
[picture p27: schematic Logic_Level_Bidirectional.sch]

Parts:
JP1, JP2: M06SIP; 1X06
JP3, JP4: FIDUCIALUFIDUCIAL; MICRO-FIDUCIAL
LOGO1: SFE_LOGO_FLAME.1_INCH; SFE_LOGO_FLAME_.1
LOGO2: OSHW-LOGOS; OSHW-LOGO-S
Q1, Q2, Q3, Q4: BSS138; SOT23-3
R1, R2, R3, R4, R5, R6, R7, R10: 10K; 0603-RES

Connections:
GND: JP1.3, JP2.4
HV: JP2.3, R4.1, R5.1, R7.1, R10.1
HV1: JP2.1, Q1.3 (D), R4.2
HV2: JP2.2, Q3.3 (D), R10.2
HV3: JP2.5, Q4.3 (D), R5.2
HV4: JP2.6, Q2.3 (D), R7.2
LV: JP1.4, Q1.1 (G), Q2.1 (G), Q3.1 (G), Q4.1 (G), R1.1, R2.1, R3.1, R6.1
LV1: JP1.6, Q1.2 (S), R3.2
LV2: JP1.5, Q3.2 (S), R2.2
LV3: JP1.2, Q4.2 (S), R1.2
LV4: JP1.1, Q2.2 (S), R6.2

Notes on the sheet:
High Voltage
Low Voltage
V01
Patrick Alberts

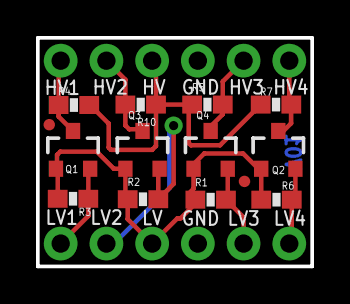
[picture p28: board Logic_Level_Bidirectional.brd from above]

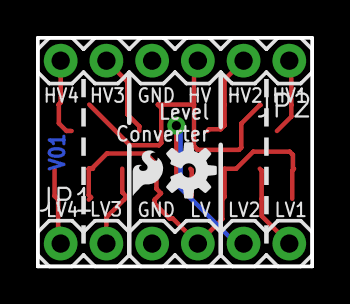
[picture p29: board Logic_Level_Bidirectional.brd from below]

Board: 2 copper layers, 15.2 x 12.7 mm, 18 parts (4 on the bottom side), 11 nets.

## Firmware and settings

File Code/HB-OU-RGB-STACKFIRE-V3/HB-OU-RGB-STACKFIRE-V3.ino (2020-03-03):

//- -----------------------------------------------------------------------------------------------------------------------
// AskSin++
// 2018-08-03 jp112sdl Creative Commons - http://creativecommons.org/licenses/by-nc-sa/3.0/de/
//- -----------------------------------------------------------------------------------------------------------------------

// define this to read the device id, serial and device type from bootloader section
// #define USE_OTA_BOOTLOADER

#define EI_NOTEXTERNAL
#include <EnableInterrupt.h>
#include <SPI.h>
#include <AskSinPP.h>
#include <LowPower.h>
#include <Register.h>

// - ---------------------------------------------------------------------------- -
// Bei der Belegung der LED-Anschlüsse 11-20                                      -
// - ---------------------------------------------------------------------------- -
#define doubleLED

// - ---------------------------------------------------------------------------- -
// Anzahl der LED's pro Augang - Arduino Mega 2560                                -
// Bei einer Belegung von 144px/m:  max. gesamt 720px                             -
//    -  max  5 x 144px (76% des dynamischen Speichers                            -
//    -  max 10 x  72px (76% des dynamischen Speichers                            -
//    -  max 20 x  36px (76% des dynamischen Speichers                            -
//  nicht belegte Ausgänge auf 1 setzen                                           -
// - ---------------------------------------------------------------------------- -
  #define WSNUM_LEDS10    30         //Anzahl angeschlossener LEDs
  #define WSNUM_LEDS11    30         //Anzahl angeschlossener LEDs
  #define WSNUM_LEDS12    30         //Anzahl angeschlossener LEDs
  #define WSNUM_LEDS13    30         //Anzahl angeschlossener LEDs
  #define WSNUM_LEDS14    30         //Anzahl angeschlossener LEDs
  #define WSNUM_LEDS15    30         //Anzahl angeschlossener LEDs
  #define WSNUM_LEDS16    30         //Anzahl angeschlossener LEDs
  #define WSNUM_LEDS17    30         //Anzahl angeschlossener LEDs        
  #define WSNUM_LEDS18    30         //Anzahl angeschlossener LEDs        
  #define WSNUM_LEDS19    30         //Anzahl angeschlossener LEDs  

#ifdef doubleLED
  #define WSNUM_LEDS20    30         //Anzahl angeschlossener LEDs 
  #define WSNUM_LEDS21    30         //Anzahl angeschlossener LEDs
  #define WSNUM_LEDS22    30         //Anzahl angeschlossener LEDs
  #define WSNUM_LEDS23    30         //Anzahl angeschlossener LEDs
  #define WSNUM_LEDS24    30         //Anzahl angeschlossener LEDs
  #define WSNUM_LEDS25    30         //Anzahl angeschlossener LEDs
  #define WSNUM_LEDS26    30         //Anzahl angeschlossener LEDs
  #define WSNUM_LEDS27    30         //Anzahl angeschlossener LEDs        
  #define WSNUM_LEDS28    30         //Anzahl angeschlossener LEDs
  #define WSNUM_LEDS29    30         //Anzahl angeschlossener LEDs  
#endif

// - ---------------------------------------------------------------------------- -
// Definition der Pin-Zuordnung                                                   -
// ACHTUNG:                                                                       -
// Bei Anpassungen darauf achten, dass je nach Konfiguration nur jeder 2. Ausgang -
// spannungstechnisch versorgt wird.                                              -
// - ---------------------------------------------------------------------------- -
  #define WSLED_PIN_10   3           //GPIO Pin LED Anschluss - Stripe 1 
  #define WSLED_PIN_11   5           //GPIO Pin LED Anschluss - Stripe 2
  #define WSLED_PIN_12   7           //GPIO Pin LED Anschluss - Stripe 3
  #define WSLED_PIN_13   9           //GPIO Pin LED Anschluss - Stripe 4
  #define WSLED_PIN_14   11          //GPIO Pin LED Anschluss - Stripe 5
  #define WSLED_PIN_15   15          //GPIO Pin LED Anschluss - Stripe 6
  #define WSLED_PIN_16   17          //GPIO Pin LED Anschluss - Stripe 7
  #define WSLED_PIN_17   19          //GPIO Pin LED Anschluss - Stripe 8        
  #define WSLED_PIN_18   20          //GPIO Pin LED Anschluss - Stripe 9        
  #define WSLED_PIN_19   21          //GPIO Pin LED Anschluss - Stripe 10   

#ifdef doubleLED
  #define WSLED_PIN_20   23          //GPIO Pin LED Anschluss - Stripe 11 
  #define WSLED_PIN_21   25          //GPIO Pin LED Anschluss - Stripe 12
  #define WSLED_PIN_22   27          //GPIO Pin LED Anschluss - Stripe 13
  #define WSLED_PIN_23   29          //GPIO Pin LED Anschluss - Stripe 14
  #define WSLED_PIN_24   31          //GPIO Pin LED Anschluss - Stripe 15   
  #define WSLED_PIN_25   22          //GPIO Pin LED Anschluss - Stripe 16
  #define WSLED_PIN_26   24          //GPIO Pin LED Anschluss - Stripe 17
  #define WSLED_PIN_27   26          //GPIO Pin LED Anschluss - Stripe 18       
  #define WSLED_PIN_28   28          //GPIO Pin LED Anschluss - Stripe 19      
  #define WSLED_PIN_29   30          //GPIO Pin LED Anschluss - Stripe 19 
#endif

  #define WSLED_TYPE    WS2812B    //LED Typ
  #define WSCOLOR_ORDER GRB        //Farbreihenfolge

  #define SLOW_PROGRAM_TIMER     30     //ms Wartezeit für den Übergang
  #define NORMAL_PROGRAM_TIMER   15     //ms Wartezeit für den Übergang
  #define FAST_PROGRAM_TIMER     0      //ms Wartezeit für den Übergang
  #define FIRE_PROGRAM_COOLING   55
  #define FIRE_PROGRAM_SPARKLING 120

//  -------------------------------------------------------------------------------------
//  - Auswahl der Flammendarstellung (siehe Fire2012/Fire2012WithPalette                -
//  -------------------------------------------------------------------------------------
// COOLING:   20 hohe Flamme ..... 100 kurze Flamme
// SPARKING:  50  mehr Flackern ..... 200 mehr Lodern
// RGBCtrl.h Zeile 748-772 RGBProgramFire1(brightness,"1-6");
//
//  Programm: Langsamer Durchlauf (1)
  #define FIRE_PRG_1_1_COOLING   60
  #define FIRE_PRG_1_1_SPARKING 180
//
//  Programm: Normaler Durchlauf (2)
  #define FIRE_PRG_1_2_COOLING  80
  #define FIRE_PRG_1_2_SPARKING 200
//
//  Programm: Schneller Durchlauf (3)
  #define FIRE_PRG_1_3_COOLING  60
  #define FIRE_PRG_1_3_SPARKING 130
//
//  Programm: Lagerfeuer (4)
  #define FIRE_PRG_2_1_COOLING  60  
  #define FIRE_PRG_2_1_SPARKING 180
//
//  Programm: Wasserfall (5)
  #define FIRE_PRG_2_2_COOLING  80
  #define FIRE_PRG_2_2_SPARKING 200
//
//  Programm: TV-Simulation (6)
  #define FIRE_PRG_2_3_COOLING  60
  #define FIRE_PRG_2_3_SPARKING 130
//  -------------------------------------------------------------------------------------

//  -------------------------------------------------------------------------------------
//  - Auswahl der Farbpalette für FirePrg2 (siehe Fire2012WithPalette                   -
//  - Standard: HeatColors_p                                                            -
//  -------------------------------------------------------------------------------------
#define GPALNR 10
//    
//  1:  static uint8_t hue = 0;
//      hue++;
//      CRGB darkcolor  = CHSV(hue,255,192); // pure hue, three-quarters brightness
//      CRGB lightcolor = CHSV(hue,128,255); // half 'whitened', full brightness
//      gPal = CRGBPalette16( CRGB::Black, darkcolor, lightcolor, CRGB::White);
//  2:  gPal = CRGBPalette256( CRGB::Black, CRGB::OrangeRed, CRGB::Red, CRGB::Yellow );
//  3:  gPal = CRGBPalette16( CRGB::Black, CRGB::Blue, CRGB::Aqua,  CRGB::White);
//  4:  gPal = CRGBPalette16( CRGB::Black, CRGB::Red, CRGB::White);    
//  5:  gPal = RainbowColors_p;
//  6:  gPal = CloudColors_p;
//  7:  gPal = PartyColors_p;
//  8:  gPal = OceanColors_p;
//  9:  gPal = CRGBPalette16( CRGB::Black, CRGB::Red, CRGB::Orange, CRGB::Yellow); //gPal = ForestColors_p;
//  10: gPal = HeatColors_p;
//  11: gPal = LavaColors_p;
//  -------------------------------------------------------------------------------------

//  -------------------------------------------------------------------------------------
//  - Auswahl der Darstellungsgeschwindigkeit                                           -
//    I recommend running this simulation at anywhere from 30-100 frames per second,    -
//    meaning an interframe delay of about 10-35 milliseconds.                          -
//  -------------------------------------------------------------------------------------
#define FRAMES_PER_SECOND 100

#if defined __AVR_ATmega2560__
#define CONFIG_BUTTON_PIN 13
#endif

#define ONBOARD_LED_PIN   4


// PINs for external Buttons
#define BTN1_PIN 6

#include "RGBCtrl.h"

#define PEERS_PER_CHANNEL 8

using namespace as;

// define all device properties
const struct DeviceInfo PROGMEM devinfo = {
  {0xFA, 0xB5, 0x01},     // Device ID
  "HB_KAMIN01",           // Device Serial
  {0xFA, 0xB5},           // Device Model
  0x25,                   // Firmware Version
  as::DeviceType::Dimmer, // Device Type
  {0x01, 0x00}            // Info Bytes
};

/**
   Configure the used hardware
*/
#if defined __AVR_ATmega2560__
typedef AskSin<StatusLed<ONBOARD_LED_PIN>, NoBattery, Radio<LibSPI<53>, 2>> HalType;
#endif

DEFREGISTER(Reg0, MASTERID_REGS, 0x20, 0x21)
class Ws28xxList0 : public RegList0<Reg0> {
  public:
    Ws28xxList0(uint16_t addr) : RegList0<Reg0>(addr) {}

    void defaults () {
      clear();
    }
};

typedef RGBLEDChannel<HalType, PEERS_PER_CHANNEL, Ws28xxList0> ChannelType;
typedef RGBLEDDevice<HalType, ChannelType, 3, Ws28xxList0> RGBLEDType;

HalType hal;
RGBLEDType sdev(devinfo, 0x20);
ConfigButton<RGBLEDType> cfgBtn(sdev);
InternalButton<RGBLEDType> btn1(sdev, 1);

void setup () {
  DINIT(57600, ASKSIN_PLUS_PLUS_IDENTIFIER);
  sdev.init(hal);
  buttonISR(cfgBtn, CONFIG_BUTTON_PIN);
  buttonISR(btn1, BTN1_PIN);

/*
  // Set frequency for CC1101
  hal.radio.initReg(CC1101_FREQ2, 0x21);
  hal.radio.initReg(CC1101_FREQ1, 0x65);
  hal.radio.initReg(CC1101_FREQ0, 0x62);
*/  
  sdev.initDone();
}

void loop() {
  bool worked = hal.runready();
  bool poll = sdev.pollRadio();
  if ( worked == false && poll == false ) {
    hal.activity.savePower<Idle<true>>(hal);
  }
  
  sdev.handleLED();
}

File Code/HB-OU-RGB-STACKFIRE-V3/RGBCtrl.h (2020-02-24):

//- -----------------------------------------------------------------------------------------------------------------------
// AskSin++
// 2017-03-29 papa Creative Commons - http://creativecommons.org/licenses/by-nc-sa/3.0/de/
// 2018-08-03 jp112sdl Creative Commons - http://creativecommons.org/licenses/by-nc-sa/3.0/de/
//- -----------------------------------------------------------------------------------------------------------------------

#ifndef __RGBLEDXX_H__
#define __RGBLEDXX_H__

#include <MultiChannelDevice.h>
#include <Register.h>
#include <FastLED.h>
#define LOGIC_INACTIVE 0
#define LOGIC_OR 1
#define LOGIC_AND 2
#define LOGIC_XOR 3
#define LOGIC_NOR 4
#define LOGIC_NAND 5
#define LOGIC_ORINVERS 6
#define LOGIC_ANDINVERS 7
#define LOGIC_PLUS 8
#define LOGIC_MINUS 9
#define LOGIC_MUL 10
#define LOGIC_PLUSINVERS 11
#define LOGIC_MINUSINVERS 12
#define LOGIC_MULINVERS 13
#define LOGIC_INVERSPLUS 14
#define LOGIC_INVERSMINUS 15
#define LOGIC_INVERSMUL 16

  CRGB leds10[WSNUM_LEDS10];
  CRGB leds11[WSNUM_LEDS11];
  CRGB leds12[WSNUM_LEDS12];
  CRGB leds13[WSNUM_LEDS13];
  CRGB leds14[WSNUM_LEDS14];
  CRGB leds15[WSNUM_LEDS15];
  CRGB leds16[WSNUM_LEDS16];
  CRGB leds17[WSNUM_LEDS17];
  CRGB leds18[WSNUM_LEDS18];
  CRGB leds19[WSNUM_LEDS19];  

#ifdef doubleLED
  CRGB leds20[WSNUM_LEDS20];   
  CRGB leds21[WSNUM_LEDS21]; 
  CRGB leds22[WSNUM_LEDS22];
  CRGB leds23[WSNUM_LEDS23];
  CRGB leds24[WSNUM_LEDS24];  
  CRGB leds25[WSNUM_LEDS25];
  CRGB leds26[WSNUM_LEDS26];
  CRGB leds27[WSNUM_LEDS27];
  CRGB leds28[WSNUM_LEDS28];
  CRGB leds29[WSNUM_LEDS29];  
#endif
  
#include "RGBPrograms.h"
#include "RGBProgramsFire.h"

namespace as {

DEFREGISTER(DimmerReg1, CREG_AES_ACTIVE, CREG_TRANSMITTRYMAX, CREG_OVERTEMPLEVEL,
            CREG_REDUCETEMPLEVEL, CREG_REDUCELEVEL, CREG_POWERUPACTION, CREG_STATUSINFO,
            CREG_CHARACTERISTIC, CREG_LOGICCOMBINATION)

class DimmerList1 : public RegList1<DimmerReg1> {
  public:
    DimmerList1 (uint16_t addr) : RegList1<DimmerReg1>(addr) {}
    void defaults () {
      clear();
      // aesActive(false);
      transmitTryMax(6);
      // powerUpAction(false);
      statusInfoMinDly(4);
      statusInfoRandom(1);

      overTempLevel(80);
      reduceTempLevel(75);
      reduceLevel(80);
      characteristic(true);
      logicCombination(LOGIC_OR);
    }
};

DEFREGISTER(DimmerReg3, PREG_CTRAMPONOFF, PREG_CTDELAYONOFF, PREG_CTONOFF,
            PREG_CONDVALUELOW, PREG_CONDVALUEHIGH, PREG_ONDELAYTIME, PREG_ONTIME,
            PREG_OFFDELAYTIME, PREG_OFFTIME, PREG_ACTIONTYPE, PREG_JTONOFF,
            PREG_JTDELAYONOFF, PREG_JTRAMPONOFF, PREG_DELAYMODE, PREG_OFFLEVEL,
            PREG_ONMINLEVEL, PREG_ONLEVEL, PREG_RAMPSTARTSTEP, PREG_RAMPONTIME,
            PREG_RAMPOFFTIME, PREG_DIMMINLEVEL, PREG_DIMMAXLEVEL, PREG_DIMSTEP,
            PREG_OFFDELAYSTEP, PREG_OFFDELAYNEWTIME, PREG_OFFDELAYOLDTIME,
            PREG_ELSEACTIONTYPE, PREG_ELSEJTONOFF, PREG_ELSEJTDELAYONOFF,
            PREG_ELSEJTRAMPONOFF)

typedef RegList3<DimmerReg3> DimmerPeerList;

class DimmerList3 : public ShortLongList<DimmerPeerList> {
  public:
    DimmerList3 (uint16_t addr) : ShortLongList<DimmerPeerList>(addr) {}
    void defaults() {
      DimmerPeerList ssl = sh();
      ssl.clear();
      //    ssl.ctRampOn(0);
      //    ssl.ctRampOff(0);
      //    ssl.ctDlyOn(0);
      //    ssl.ctDlyOff(0);
      //    ssl.ctOn(0);
      //    ssl.ctOff(0);
      ssl.ctValLo(0x32);
      ssl.ctValHi(0x64);
      //    ssl.onDly(0);
      ssl.onTime(0xff);
      //    ssl.offDly(0);
      ssl.offTime(0xff);
      ssl.actionType(AS_CM_ACTIONTYPE_JUMP_TO_TARGET);
      //    ssl.offTimeMode(false);
      //    ssl.onTimeMode(false);
      ssl.offDelayBlink(true);
      //    ssl.offLevel(0);
      ssl.onMinLevel(20);
      ssl.onLevel(200); // 201 ???
      ssl.rampStartStep(10);
      //    ssl.rampOnTime(0);
      //    ssl.rampOffTime(0);
      //    ssl.dimMinLevel(0);
      ssl.dimMaxLevel(200);
      ssl.dimStep(5);
      ssl.offDelayStep(10);
      ssl.offDelayNewTime(5);
      ssl.offDelayOldTime(5);
      ssl.elseActionType(AS_CM_ACTIONTYPE_INACTIVE);
      //    ssl.elseOffTimeMode(false);
      //    ssl.elseOnTimeMode(false);
      ssl.elseJtOn(AS_CM_JT_ONDELAY);
      ssl.elseJtOff(AS_CM_JT_ONDELAY);
      ssl.elseJtDlyOn(AS_CM_JT_ONDELAY);
      ssl.elseJtDlyOff(AS_CM_JT_ONDELAY);
      ssl.elseJtRampOn(AS_CM_JT_ONDELAY);
      ssl.elseJtRampOff(AS_CM_JT_ONDELAY);

      ssl = lg();
      ssl.clear();
      //    ssl.ctRampOn(0);
      //    ssl.ctRampOff(0);
      //    ssl.ctDlyOn(0);
      //    ssl.ctDlyOff(0);
      //    ssl.ctOn(0);
      //    ssl.ctOff(0);
      ssl.ctValLo(0x32);
      ssl.ctValHi(0x64);
      //    ssl.onDly(0);
      ssl.onTime(0xff);
      //    ssl.offDly(0);
      ssl.offTime(0xff);
      ssl.actionType(AS_CM_ACTIONTYPE_JUMP_TO_TARGET);
      ssl.multiExec(true);
      //    ssl.offTimeMode(false);
      //    ssl.onTimeMode(false);
      ssl.offDelayBlink(true);
      //    ssl.offLevel(0);
      ssl.onMinLevel(20);
      ssl.onLevel(200); // 201 ???
      ssl.rampStartStep(10);
      //    ssl.rampOnTime(0);
      //    ssl.rampOffTime(0);
      //    ssl.dimMinLevel(0);
      ssl.dimMaxLevel(200);
      ssl.dimStep(5);
      ssl.offDelayStep(10);
      ssl.offDelayNewTime(5);
      ssl.offDelayOldTime(5);
      ssl.elseActionType(AS_CM_ACTIONTYPE_INACTIVE);
      //    ssl.elseOffTimeMode(false);
      //    ssl.elseOnTimeMode(false);
      ssl.elseJtOn(AS_CM_JT_ONDELAY);
      ssl.elseJtOff(AS_CM_JT_ONDELAY);
      ssl.elseJtDlyOn(AS_CM_JT_ONDELAY);
      ssl.elseJtDlyOff(AS_CM_JT_ONDELAY);
      ssl.elseJtRampOn(AS_CM_JT_ONDELAY);
      ssl.elseJtRampOff(AS_CM_JT_ONDELAY);
    }

    void odd() {
      defaults();
      DimmerPeerList ssl = sh();
      ssl.jtOn(AS_CM_JT_OFFDELAY);
      ssl.jtOff(AS_CM_JT_OFF);
      ssl.jtDlyOn(AS_CM_JT_RAMPOFF);
      ssl.jtDlyOff(AS_CM_JT_RAMPOFF);
      ssl.jtRampOn(AS_CM_JT_RAMPOFF);
      ssl.jtRampOff(AS_CM_JT_OFF);
      ssl = lg();
      ssl.actionType(AS_CM_ACTIONTYPE_DOWNDIM);
    }

    void even() {
      defaults();
      DimmerPeerList ssl = sh();
      ssl.jtOn(AS_CM_JT_ON);
      ssl.jtOff(AS_CM_JT_ONDELAY);
      ssl.jtDlyOn(AS_CM_JT_RAMPON);
      ssl.jtDlyOff(AS_CM_JT_RAMPON);
      ssl.jtRampOn(AS_CM_JT_ON);
      ssl.jtRampOff(AS_CM_JT_RAMPON);
      ssl = lg();
      ssl.actionType(AS_CM_ACTIONTYPE_UPDIM);
    }

    void single() {
      defaults();
      DimmerPeerList ssl = sh();
      ssl.jtOn(AS_CM_JT_OFFDELAY);
      ssl.jtOff(AS_CM_JT_ONDELAY);
      ssl.jtDlyOn(AS_CM_JT_RAMPON);
      ssl.jtDlyOff(AS_CM_JT_RAMPOFF);
      ssl.jtRampOn(AS_CM_JT_ON);
      ssl.jtRampOff(AS_CM_JT_OFF);
      ssl = lg();
      ssl.actionType(AS_CM_ACTIONTYPE_TOGGLEDIM_TO_COUNTER);
    }

};


class DimmerStateMachine {
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

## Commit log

2020-02-01 Image PCB
    [HB-OU-RGB-STACKFIRE.kicad_pcb]
2020-02-02 Images Aufbau
    [Stack-Fire-Leuchte_Sockel_Platine_V1.stl]
2020-02-18 del ws2812B
    [WS2812B-Protect-B.Cu.gbr, WS2812B-Protect-B.Mask.gbr, WS2812B-Protect-B.Paste.gbr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]
2020-02-24 Rev 3.0.1 wit external Button (Test)
    [HB-OU-RGB-STACKFIRE-B.Cu.gbr, HB-OU-RGB-STACKFIRE-B.Mask.gbr, HB-OU-RGB-STACKFIRE-B.SilkS.gbr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]

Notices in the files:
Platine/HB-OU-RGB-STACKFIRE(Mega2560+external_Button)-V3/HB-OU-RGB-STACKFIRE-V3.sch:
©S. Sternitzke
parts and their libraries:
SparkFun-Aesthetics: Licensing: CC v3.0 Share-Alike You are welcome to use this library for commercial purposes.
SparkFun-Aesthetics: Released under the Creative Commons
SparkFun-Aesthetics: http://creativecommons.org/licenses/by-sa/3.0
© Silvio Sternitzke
